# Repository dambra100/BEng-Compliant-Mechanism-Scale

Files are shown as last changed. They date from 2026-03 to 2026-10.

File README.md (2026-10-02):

# Optical Force Tracking: Compliant Mechanism Scale





This repository contains the software architecture, CAD, and raw datasets for a low-cost optical tracking scale. The system explores the replacement of expensive mechanical load cells with compliant mechanisms and computer vision (tracking planar displacements via a standard webcam).

**📄 Submitted for peer review to IEEE Sensors Letters; not accepted for publication. A preprint is publicly available on TechRxiv (August 2023). The submitted manuscript is also included in the `/Documents` directory.**

## 🔬 Core Technologies

### 1. Mechanical Design & FEA
The scale utilises a custom 3D-printed compliant mechanism. Extensive Finite Element Analysis (FEA) was conducted to ensure the flexure legs operate strictly within the elastic region of the PLA material, guaranteeing repeatability and preventing mechanical yielding under load.

### 2. Optical Tracking & GUI (MATLAB)
The system tracks physical planar displacements using high-contrast optical markers. 
* A custom MATLAB GUI (`gui.m`) segments the live video feed into four distinct quadrants.
* The software calculates 12 real-time state variables (pixel areas and centroid X/Y coordinates) to track micro-deformations.

### 3. Mathematical Calibration (Machine Learning)
Using Multiple Linear Regression (MLR) trained on 99 physical test samples, the system generates a `3×12` calibration matrix. 

## ⚙️ Engineering Workflow

* **Theoretical Validation:** Computational stress limits were established using CAD and FEA.
* **Physical Assembly:** The compliant mechanism was 3D printed and assembled with high-contrast optical markers.
* **Data Acquisition:** Eccentric load testing was conducted to capture raw displacement telemetry via the MATLAB computer vision interface.
* **Mathematical Isolation:** The calibration matrix successfully calculates absolute mass ($F_z$) while mathematically ignoring bending moments ($M_x, M_y$) caused by off-centre loads.

## 📁 Repository Structure

* `/CAD/` - Iterative design files (`.step`) and final 3D printing meshes (`.stl`).
* `/Documents/` - Final BEng dissertation report and the IEEE Sensors Letters submission manuscript (not accepted for publication; preprint available on TechRxiv).
* `/Images/` - Visual assets for physical assembly, FEA modelling, and GUI demonstration.
* `/Scripts/` - Core MATLAB optical tracking (`gui.m`), machine learning calibration, and plotting scripts.
* `ALL_IN_ONE.xlsx` - The raw 99-sample calibration and validation dataset.
* `README.md` - Project documentation.

## 📊 Execution & Results

### Physical Assembly & Hardware Testing
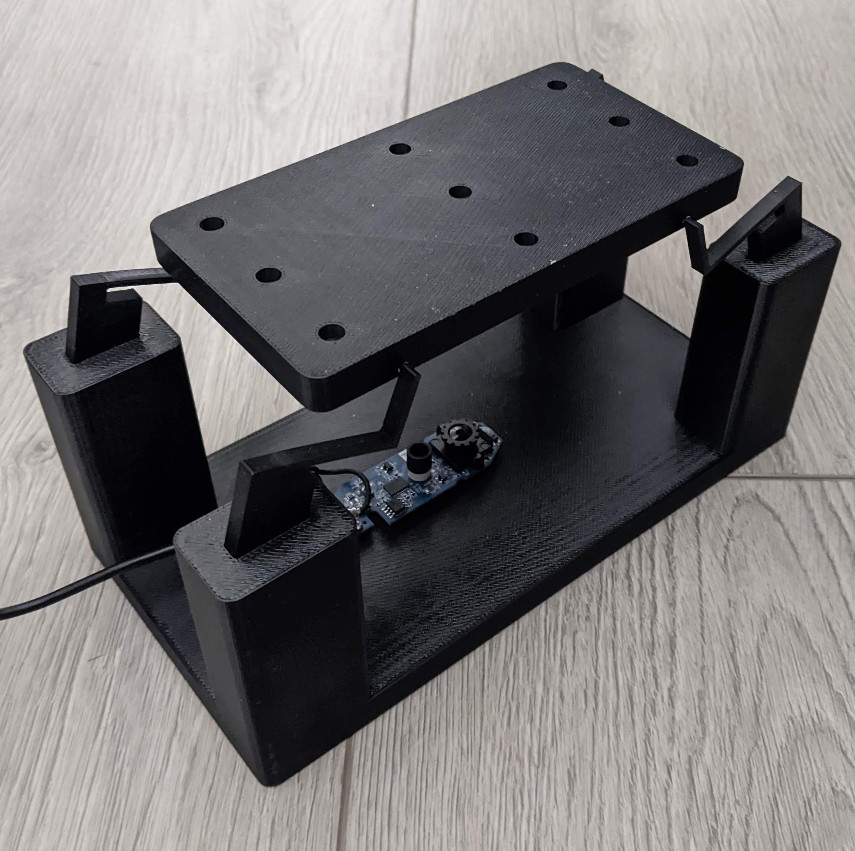
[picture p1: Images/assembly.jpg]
Physical Assembly

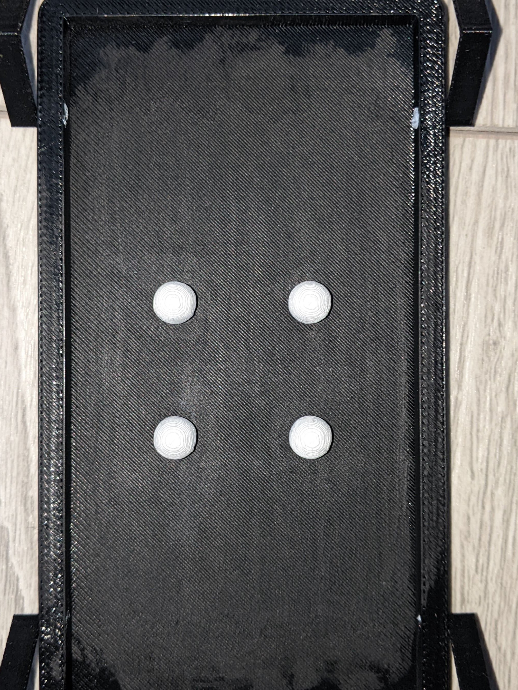
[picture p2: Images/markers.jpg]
Optical Tracking Markers

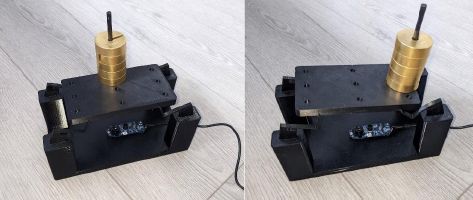
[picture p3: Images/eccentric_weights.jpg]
Eccentric Weights Testing


### FEA Stress Analysis
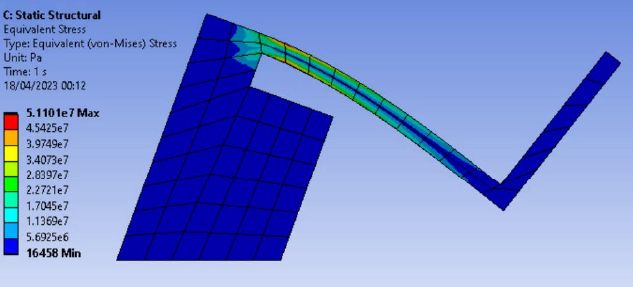
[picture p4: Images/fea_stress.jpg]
FEA Analysis


### Digital Pipeline & Validation
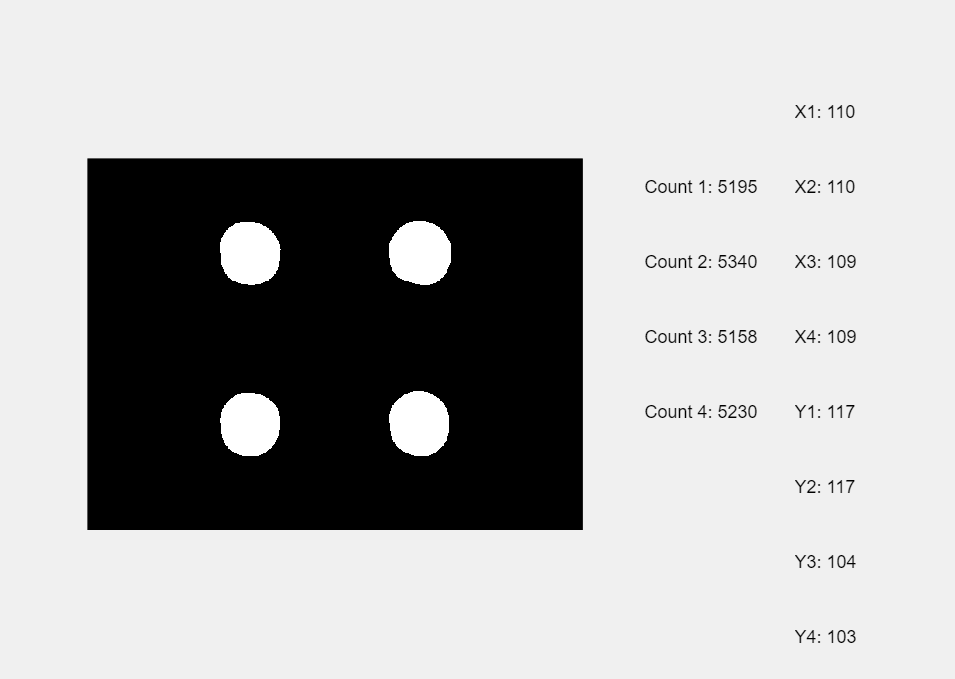
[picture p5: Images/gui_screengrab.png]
MATLAB GUI

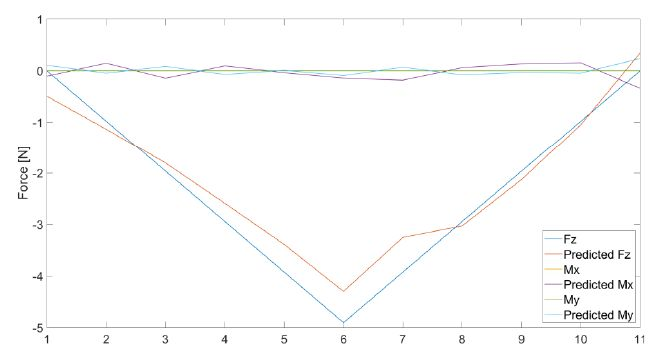
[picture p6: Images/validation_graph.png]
Performance Graph


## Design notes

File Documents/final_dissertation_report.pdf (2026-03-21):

DEPARTMENT OF MECHANICAL AND AEROSPACE ENGINEERING

FINAL PROJECT REPORT for

Development of a low-cost portable scale with a smartphone

by

Mohammad Zeshaan Shahid

Student ID: 1914982

Supervisor: Yohan Noh

Submitted in part fulfilment of the requirements for

the degree of Bachelors of Engineering

in

Mechanical Engineering

APRIL 2023

i

DECLARATION

I declare that the work in this project was carried out in accordance with the

requirements of the University’s Regulations and Code of Practice for Taught

Programmes and that it has not been submitted for any other academic award. Except

where indicated by specific reference in the text, this work is my own work. Work done

in collaboration with, or with the assistance of others, is indicated as such. I have

identified all material in this dissertation report that is not my own work through

appropriate referencing and acknowledgement. Where I have quoted or otherwise

incorporated material, which is the work of others, I have included the source in the

references. Any views expressed in the dissertation, other than referenced material,

are those of the author.

SIGNED: | | DATE: 01/03/23

ABSTRACT

This project aims to develop a low-cost portable scale using a smartphone. The project is

carried out to show that image processing technology can be used as a tool to find the weight

of an object. The project was carried out by 3D printing a platform on which a PCB of a webcam

was mounted. The webcam would then observe four white markers on a black surface, and

when a mass is placed on the platform the size of each marker and the distance of each

marker from the middle point can be found using the Image Processing Toolbox on MATLAB.

Using this data the mass can be found. In order to calibrate the sensor fixed masses are

placed. The main conclusion of this project is that it shows that an image-processing tool can

be effectively used to find the mass of an object.

ii

ACKNOWLEDGEMENTS

I would like to thank Professor Yohan Noh for their continued support throughout this project.

iii

TABLE OF CONTENTS

KEYWORDS | Error! Bookmark not defined.

iv

Appendices | XLI
Appendix A – Management of the Project | XLI
Appendix A.1 Project Gantt Chart | XLII

XLII

Appendix B – GUI MATLAB Script | XLIII
Appendix C – Plotting MATLAB Script | XLVI
Appendix D – Calibration MATLAB Script | XLIX
Appendix E – Risk Assessment | LII

v

LIST OF FIGURES

Figure Ref Title | Page

Figure 25: Characteristic curve between the loads Fz Mx, and the pixel count........ 29

Figure 28. Comparison between real Fz Mx and estimated Fz Mx (Positive Mx ).... 30

Figure 29. Comparison between real Fz Mx and estimated Fz Mx (Negative Mx ) .. 31

Figure 30. Comparison between real Fz My and estimated Fz My (Positive My ).... 31

vi

Figure 31:. Comparison between real Fz My and estimated Fz My (Negative My) .. 31

LIST OF TABLES

Table Ref Title | Page

vii

NOMENCLATURE

Abbreviations

CAD – Computer Aided Design

FEA – Finite Element Analysis

3D – Three-Dimensional

PLC – Programmable Logic Controller

RGB – Red, Green, Blue

CNN – Convolutional Neural Network

SVM – Support Vector Machine

HSV – Hue, Saturation, Value

BGR – Blue, Green, Red

MBR – Minimum Bounding Rectangle

GLCM – Grey-Level Co-occurrence Matrix

GUI - Graphical User Interface

### 1 Introduction

The development of portable weighing scales has become increasingly important in

many industries, such as agriculture, food processing, and shipping. These scales

allow for accurate and efficient weighing of goods, minimizing the risk of error and

reducing costs. However, the cost of traditional weighing scales can be prohibitive for

many small businesses and individuals. Additionally, traditional scales can be bulky

and difficult to transport, limiting their usefulness in certain contexts. To address these

challenges, this dissertation focuses on the development of a low-cost, portable scale

that utilizes a smartphone and an image processing tool to accurately measure the

mass of objects. By using a smartphone camera and a custom image processing

algorithm, this scale offers a low-cost, flexible, and user-friendly solution for measuring

the mass of goods in a variety of settings. The research presented in this dissertation

aims to demonstrate the feasibility and effectiveness of this approach and to explore

the potential applications and benefits of such a technology in various industries.

### 1.1 Context for the project

This project is relevant to the degree course in Mechanical Engineering because it

requires the use of the following:

- CAD Software
- Computer Language
- FEA Software

This project will enhance the strengths of the listed software, all of which are commonly

required in the industry.

A CAD software is needed to design the scale's portable folding/unfolding mechanism.

A computer language is needed to use an image-processing tool, which will be used

to read the number of pixels under the plate of the scale and the distance from the

centre point. An FEA software is needed to identify a suitable material and design for

the mechanism as it must remain in the elastic region when under loads of up to 5N.

The industrial relevance of this project is that it means people will be able to use this

device to weigh things without needing an actual scale. All they need is this device

and a smartphone, so unlike traditional small electrical scales, there is no need for any

batteries. Instead, all they need is a charged smartphone that has a camera.

The coding language MATLAB will be used because it is based on a matrix data

structure which makes it ideal for image processing. Image processing operations that

might require many lines of code in other coding languages can be expressed in a

single line of MATLAB code.

The CAD software that will be used is Fusion 360. Fusion 360 will be used because

of prior knowledge on the software. Other advantages of Fusion 360 are that it has

cloud based saving and also has a wide range design tools which makes creating

complex geometries easier

The FEA software of choice will be Ansys Workbench as it has a good interface and

is easy to use. It also has a wide range of simulation capabilities and advanced

material modelling.

There can offer many commercial aspects of this project as having a small portable

weighing scale that uses a smartphone and an image processing tool would be:

Convenient: The scale will be able to be easily carried around, making it convenient

to weigh small items on the go.

Cost-effectiveness: It can be produced at a lower cost compared to traditional

weighing scales

Accuracy: Using an image processing tool the scale can achieve a higher accuracy

meaning it can be used for scientific medical and industrial purposes.

Flexibility: The scale can be used with a variety of smartphones and other mobile

devices, making it more versatile and adaptable to the needs of various users.

There are current weighing scales which use image processing technology on the

market but they tend to use edge detection and pattern recognition rather than

observing different markers. Many smartphones do not have the computational

power or the memory capacity to perform pattern recognition as it typically involves

training a machine learning algorithm.

### 1.2 Aim and objectives for the project

The aim of this project is to develop a low-cost portable scale that utilizes a

smartphone and an image processing tool to accurately measure the mass of objects.

The specific aims of this project are:

- To develop an image processing algorithm that accurately measures the mass

of objects using a smartphone camera.

- To design and develop a prototype of the portable scale that incorporates the

image processing algorithm.

- To evaluate the accuracy and precision of the portable scale in comparison to

traditional weighing scales.

- To explore the potential applications of the portable scale in various industries,

including agriculture, food processing, and shipping.

To achieve the aims of this project, the following objectives will be pursued:

- Conduct a comprehensive literature review of existing portable scales, image

processing algorithms, and smartphone-based measurement tools.

- Develop an image processing algorithm that can accurately measure the mass

of objects using a smartphone camera.

- Design and develop a prototype of the portable scale that incorporates the

image processing algorithm.

- Test the accuracy and precision of the portable scale by comparing it to

traditional weighing scales using a range of objects and masses.

- Write a report summarizing the findings of the project and making

recommendations for future development and implementation of the portable

scale.

### 2 Literature Review

### 2.1 Introduction

This literature review focuses on a project that aims to create a low-cost portable scale

using a smartphone and image processing technology. The primary objective of the

review is to provide a comprehensive overview of the existing knowledge, techniques,

and technologies relevant to the proposed project. It will explore a range of topics,

including smartphone-based measurement tools, the use of image processing

techniques, current calibration and validation methods, and related works in the field,

to demonstrate the feasibility of the proposed project and provide a solid foundation

for its development.

### 2.2 Background

The importance of accurate and convenient weight measurement systems cannot be

understated, as they play a critical role in various industries. Traditional weight

measurements devices, such as mechanical scales, electronic balances, and load

cells, are widely used but often come with limitations in terms of cost, portability, and

ease of use. With the rapid advancement of technology, there is a growing interest in

developing alternative, low-cost, and portable solutions that leverage the power of

smartphones and image-processing technology. Despite these technological

advancements, there are still challenges and limitations to overcome in developing an

accurate and reliable low-cost portable scale based on smartphones and image

processing technology. This literature review aims to provide a comprehensive

understanding of the current state of the field and the relevant technologies, such as

portable scales, image processing techniques, smartphone technology and sensors,

and calibration methods. By identifying the gaps and limitations in existing

approaches, this review will lay the foundation for the development of a low-cost

portable scale using a smartphone and image processing technology, with the

potential to revolutionize weight measurement systems.

### 2.3 Smartphone-based Measurement Systems

Over the past few years, smartphones have evolved into highly advanced,

multifunctional devices equipped with a plethora of sensors and processing

capabilities. This rapid development has allowed researchers and engineers to

leverage smartphones for various measurement systems, utilizing their in-built

sensors, computing power, and portability. In this section, we will discuss the current

state of smartphone-based measurement systems, highlighting their applications,

advantages, and limitations.

### 2.3.1 Applications of Smartphone-based Measurement Systems

Smartphone-based measurement systems have found applications across diverse

fields such as healthcare, transportation, environmental monitoring, and industrial

automation. Some notable examples include:

Health monitoring: Smartphones have been used to monitor heart rate, blood

pressure, and physical activity levels using in-built or external sensors. Mobile

applications have also been developed for diagnosing and managing chronic

conditions such as diabetes or sleep disorders. For instance, Cardiio is a mobile app

that uses a smartphone's camera to measure an individual's heart rate through non-

contact photoplethysmography. [1] [2]

Transportation and navigation: Smartphones' integration of GPS, accelerometers, and

gyroscopes has facilitated precise location tracking and navigation capabilities,

enabling better transportation management and route optimization. Google Maps is a

prominent example of smartphones being used for this purpose. [3]

Environmental monitoring: Smartphone sensors such as microphones and cameras

have been employed to assess noise pollution, air quality, and other environmental

factors in real time. For example, the AirVisual app provides real-time air quality data,

forecasts, and historical trends by aggregating data from various sources. [4]

Industrial automation: Smartphones have been used as data acquisition and control

devices in industrial processes, enabling remote monitoring, maintenance, and

efficient resource management. Mobile apps for Programmable Logic Controllers

(PLCs) are an example of smartphones being used in industrial automation. These

apps communicate with the PLCs through wireless networks, allowing users to access

the PLC from anywhere with an internet connection. [5]

### 2.3.2 Advantages of Smartphone-based Measurement Systems

The increasing popularity of smartphone-based measurement systems can be

attributed to several advantages they offer:

Cost-effectiveness: As smartphones are widely available and include multiple sensors,

their utilization in measurement systems can reduce the need for dedicated, costly

hardware.

Portability: The compact and lightweight nature of smartphones enables users to carry

and deploy measurement systems effortlessly, facilitating measurements in various

locations and scenarios.

Accessibility: Smartphone-based measurement systems can reach a broader

audience, given the widespread use of smartphones worldwide. This accessibility can

potentially enhance data collection, knowledge sharing, and problem-solving across

different domains.

Versatility: The combination of diverse sensors and powerful processing capabilities

in smartphones allows for versatile measurement systems, capable of addressing a

wide range of applications.

### 2.3.3 Limitations of Smartphone-based Measurement Systems

Despite the numerous advantages, there are certain limitations to consider when using

smartphones for measurement systems:

Sensor accuracy and variability: The accuracy of sensors embedded in smartphones

can vary between different devices and models, potentially affecting the reliability of

the measurement system.

Power consumption: Continuous use of sensors and processing capabilities can drain

the smartphone's battery, limiting the measurement system's operational time.

Data privacy and security: The use of smartphones for data collection and

transmission may raise concerns about data privacy and security, necessitating robust

data protection mechanisms.

In conclusion, smartphone-based measurement systems offer a cost-effective,

portable, and accessible alternative to traditional measurement tools. By

understanding and mitigating their limitations, these systems can significantly impact

various industries, enhancing efficiency and decision-making processes. The low-cost

portable scale developed in this project is one such example of an innovative

smartphone-based measurement system, showcasing the potential of image

processing technology in estimating object weight.

### 2.4 Image Processing for Weight Estimation

Image processing has become an essential tool in various fields due to advancements

in computer vision and machine learning techniques. The capability of extracting

meaningful information from images has led researchers to explore the potential of

using image processing for weight estimation and other physical property

measurements. In this section, we will discuss the different approaches and

methodologies adopted in the literature for weight estimation using image processing

techniques.

### 2.4.1 Approaches for Weight Estimation

Several approaches have been proposed to estimate an object's weight based on its

appearance in images. Some of the most common methods include Shape and size

analysis: By analysing the object's shape and size in images, researchers can develop

models to estimate the object's weight. For instance, the size of fruits or fish has been

correlated with their weight, allowing for weight estimation based on their dimensions

in images. [6] [7]

Volume estimation: In some cases, the weight of an object can be estimated by first

calculating its volume from images. Techniques such as stereo vision or depth sensors

can be employed to obtain 3D information and subsequently calculate the volume of

the object. This approach has been used for estimating the weight of irregularly

shaped objects, such as logs or rocks. [8] [9]

Deformation analysis: Another approach for weight estimation is based on observing

the deformation of an object or a supporting structure caused by the object's weight.

In the context of this project, image processing is used to track the displacement of

markers on a platform due to an object's weight. The displacement data can then be

used to infer the object's mass. [10]

Machine learning and deep learning: Advanced machine learning and deep learning

techniques, such as Convolutional Neural Networks (CNNs) and Support Vector

Machines (SVMs), have been used for weight estimation tasks. These algorithms can

learn complex patterns and relationships between image features and object weight

through training on large datasets. [11]

### 2.4.2 Challenges and Considerations

While image processing techniques have shown promise for weight estimation tasks,

there are several challenges and considerations to take into account:

Calibration and accuracy: Ensuring accurate weight estimation through image

processing requires proper calibration and validation using ground truth data. This can

be achieved by using known masses during the development and testing phases of

the system.

Image quality and lighting conditions: The accuracy of weight estimation can be

affected by variations in image quality and lighting conditions. It is crucial to consider

these factors while designing the measurement setup and developing the image

processing algorithms.

In summary, image processing techniques offer a promising alternative for weight

estimation tasks. By understanding and addressing the challenges and considerations

discussed in this section, accurate and reliable weight estimation can be achieved

using image-based methodologies. The project presented in this dissertation is a

testament to the potential of image processing technology in determining the mass of

an object through marker displacement analysis.

### 2.5 MATLAB Image Processing Toolbox

The Image Processing Toolbox is a comprehensive suite of tools and functions

available in MATLAB for processing, analysing, and visualizing images. The toolbox

offers a wide range of algorithms for various image-processing tasks, such as image

enhancement, segmentation, transformation, and feature extraction. In this section,

we will discuss the key features and capabilities of the MATLAB Image Processing

Toolbox and its relevance to the low-cost portable scale project using a smartphone.

### 2.5.1 Key Features and Capabilities

The MATLAB Image Processing Toolbox provides several features and capabilities

that facilitate image processing and analysis, including:

Image enhancement: The toolbox offers a variety of algorithms for enhancing image

quality, such as noise reduction, contrast adjustment, and filtering techniques. These

functions help improve the image's visual appearance, making it easier to analyse and

extract relevant information. [12]

Image segmentation: Segmentation is the process of dividing an image into

meaningful regions or objects. The Image Processing Toolbox provides various

segmentation algorithms, such as thresholding, region growing, and edge detection,

to separate and identify objects within an image. [13]

Spatial transformations: The toolbox includes functions for performing spatial

transformations on images, such as resizing, rotating, and warping. These functions

are useful for image registration, alignment, and geometric correction. [14]

Feature extraction: The Image Processing Toolbox allows for the extraction of features

from images, such as corners, edges, and blobs. These features can be used to

analyse the properties of objects in images or as input for machine learning algorithms.

[15]

Colour space conversion: The toolbox supports the conversion of images between

various colour spaces, such as RGB, HSV, and YCbCr. This functionality is useful for

colour-based image processing tasks, such as object recognition and tracking. [16]

### 2.5.2 Relevance to the Portable Scale Project

In the context of the low-cost portable scale project using a smartphone, the MATLAB

Image Processing Toolbox is employed for processing the images captured by the

smartphone camera and estimating the mass of objects based on marker size and

displacement. The toolbox's capabilities are particularly relevant in the following

aspects:

Image pre-processing: Enhancing the image quality by reducing noise, adjusting

contrast, and correcting lighting conditions, which is essential for accurate marker

detection and tracking.

Marker detection and tracking: The toolbox's segmentation, feature extraction, and

morphological operations can be used to identify and track the position of the four

white markers on the black surface.

Geometric transformations and analysis: The toolbox provides functions for calculating

the size of each marker, the distance between markers, and the displacement caused

by the mass placed on the platform. These measurements can be used to estimate

the object's mass.

In summary, the MATLAB Image Processing Toolbox offers a comprehensive set of

tools and functions for processing and analysing images, making it an essential

component of the low-cost portable scale project using a smartphone. By leveraging

the toolbox's capabilities, the project demonstrates the potential of image processing

technology as an effective tool for estimating the mass of objects based on marker

displacement analysis.

### 2.6 Previous Studies

Looking at previous studies, current methods using image processing tools to weigh

objects tend to focus on systems designed to weigh specific objects, rather than a

range of objects like traditional weighing scales. There is also currently no small

weighing scale that uses image processing.

An example of a study that used image processing study was carried out by

Duangkamol Dangphonthong and Wasan Pinate which uses the following method to

analyse the image and estimate the weight of an egg:

First, a colour image of the egg is captured using a digital camera, resulting in an RGB

image with a resolution of 3,000 x 4,000 pixels. The egg is placed in various positions

to test the accuracy of weight estimation.

Second, image sharpening is performed to adjust the contrast of the image. The

contrast is adjusted by determining the position of intensity changes, enabling the clear

identification of the object's edges.

Third, image representation is used to separate the relevant parts of the image, with

region representation used in this research. The egg's area is represented by the

number 1, while other areas are represented by the number 0.

Fourth, regional descriptors are used to determine the basic features of the object,

such as width, length, height, shape, and surface. In this research, the width and length

of the egg are calculated using the distance formula.

Fifth, egg weight and volume are computed using various equations proposed by

different researchers. This study uses the fourth equation to estimate egg volume, and

the extrapolation method is used to estimate egg weight based on the relationship

between weight and volume.

Finally, recognition involves sorting egg size by weight and comparing the analysed

egg weight with the agricultural commodity and food standard. This helps in classifying

the eggs according to their sizes. [17]

Another example of a study that used image processing was carried out by Sharma,

R., Kumar, M. & Alam, M.S. which uses the following method to categorize wheat

samples into sound, damaged, shrivelled, and broken grains:

First, the acquired colour images in BGR format were converted into three 8-bit

grayscale images, representing the blue, green, and red bands. This simplifies the

analysis by reducing the amount of data to be processed and focusing on intensity

values.

Next, a low-pass Gaussian filter with a 5x5 kernel size was applied to the grayscale

images to remove small discrepancies or noise, ensuring smoothness and preserving

the important details in the images. After that, the combined thresholding algorithm of

binary and Otsu operator was applied for background segmentation using the OpenCV

threshold function. This technique helps in separating the desired object, such as

wheat grain, from the background. Binary thresholding was used for other refractions,

like damaged, shrivelled, and broken grains.

A mask was created based on the threshold values, and bitwise operations were

performed to keep only the pixels in the desired range, thus segmenting the grains

effectively. Following this, OpenCV's CHAIN_APPROX_NONE function was used to

detect the contours of each binary image of grain. This step involves finding the

boundaries of the grains in the images, which are then used for extracting size, shape,

colour, and texture features.

RGB images were converted to HSV (Hue, Saturation, Value) colour space using

OpenCV's BGR2HSV function. The HSV model is closer to human colour perception,

making it more suitable for colour feature extraction.

Finally, a range of features was extracted using OpenCV library functions, including

area, perimeter, solidity, minimum bounding rectangle (MBR), major and minor

diameter, equivalent diameter, and more. Additionally, colour and texture feature like

grey-level co-occurrence matrix (GLCM) were extracted using the skimage library.

These image processing techniques allowed for the systematic extraction of size,

shape, colour, and texture features of the wheat kernels, which are essential for

various analysis and classification tasks in agriculture. [18]

### 3 Methodology

### 3.1 Introduction

The methodology section of this project provides a detailed and systematic description

of the steps and processes followed to develop a low-cost portable scale using a

smartphone's rear camera and a folding/unfolding mechanism. This section aims to

ensure that the project's approach is transparent and reproducible, allowing others to

understand, evaluate, and potentially build upon the work. In this section, we will

outline the methods used for selecting the appropriate CAD software and

programming language, designing and refining the portable scale and folding

mechanism, implementing the computer vision application and graphical user

interface (GUI), and calibrating and validating the system's performance.

### 3.2 Selection of CAD Software and Programming Language

To select the most suitable CAD software and programming language for this project,

a set of criteria was established to evaluate and compare the available options. These

criteria included ease of use, availability of tutorials and resources, compatibility with

computer vision libraries and integration capabilities.

### 3.2.1 Selection of CAD Software

After considering various CAD software packages, including CREO, Fusion 360,

Onshape, Solidworks, and Ansys, Fusion 360 was chosen for the following reasons:

Fusion 360 is a CAD software that offers several benefits to its users. One of its

advantages is its user-friendly interface, which makes it easier for new users to learn

and become proficient in designing. Additionally, Fusion 360's cloud-based

functionality enables seamless collaboration and remote access to project files,

making it convenient for teams working on the same project. The software also offers

comprehensive features that include parametric design, direct modelling, assembly,

and FEA capabilities, which help streamline the design process. Moreover, Fusion 360

has a strong community support system, which includes an active user community and

a wealth of online resources such as tutorials and forums that provide assistance in

the learning process and troubleshooting support.

### 3.2.2 Selection of Programming Language

When evaluating programming languages, options like Python, C++, C#, and MATLAB

were considered. MATLAB was chosen due to the following factors:

MATLAB is a programming language that offers several advantages for image

processing and computer vision tasks. One of its strengths is its extensive library

support, which includes built-in functions and toolboxes such as the Image Processing

Toolbox and Computer Vision Toolbox, that are well-suited for these tasks.

Additionally, MATLAB's syntax is straightforward and easy to understand, promoting

the development of complex algorithms and reducing the likelihood of coding errors.

The software also provides comprehensive documentation and has an active user

community, which makes it easier to find solutions and guidance for implementing

specific functions and algorithms. Overall, MATLAB is a powerful tool for image

processing and computer vision tasks that offers simplicity, readability, and strong

community support.

In conclusion, Fusion 360 and MATLAB were selected for this project based on their

user-friendly interfaces, compatibility with each other, comprehensive features and

strong community support. These tools provide an ideal foundation for the

development of the low-cost portable scale system using a smartphone's rear camera

and a folding/unfolding mechanism.

### 3.3 Conceptual design and design refinement

The key concept from the beginning was that there will be a camera looking up at a

surface which has four different spherical markers. When a mass is placed on the main

body, the legs of the mechanism will deform, causing the size of the markers to

increase. Based on the sizes of the markers the weight will be calculated. Later in the

project, to improve the accuracy of the scale, the distance of these four markers from

the centre point was also used. By calculating the X and Y distance of each marker,

the calibration matrix goes from 3x4 to 3x12.

The first mechanism that needed to be designed was the folding and unfolding

mechanism. The initial inspiration for the final design is taken from folding picnic tables

like the one seen below in Figure 1

Figure 1: Folding picnic table [19]

Next, a design for the leg had to be created. The leg design had to be created so that

the mechanism can deform under loads of up to 500g and stay within the elastic

region. To create different concepts for the leg Autodesk Fusion 360 was used. Below

in Figure 2 you can see the leg designs that were considered to take into further testing

using FEA:

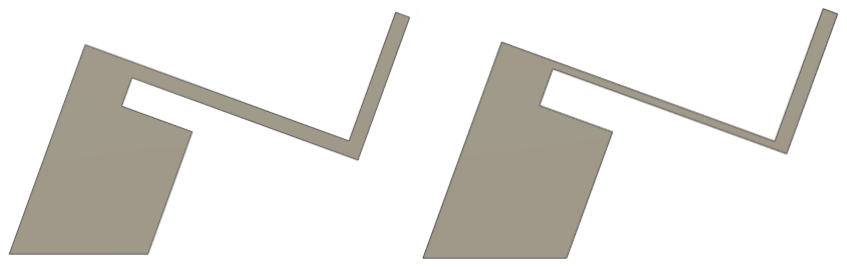
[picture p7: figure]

Figure 2: Concept leg designs

The inspiration for the leg designs was cantilever beams, this is because cantilever

beams have many advantages, the key advantage in this application is that they offer

large deflection. Greater deflection is beneficial because it means a greater change in

pixel size and distance making the scale accurate for smaller masses. Another

advantage of the cantilever beam is that it doesn’t require support on the opposite

side. The cantilever beam design also means the deformation can be controlled and

predicted.

Later, due to the irregular shape of the legs rather than having the leg fold, it was

chosen to have the supports of the base fold instead. The folding mechanism can be

seen later in Figure 4. The legs are able to fold due to the hinge, as the hinge is very

thin it is able to easily fold and unfold. If the product was to be mass-produced a metal

hinge would likely be used to ensure the longevity of the product.

The main body for the scale was designed next, with the legs and base taken into

consideration. The body is designed with 9 holes used to place a cylinder which will

be used later for the calibration process. The main body is also designed with 4 holes

on the sides seen later in Figure 5 to connect the legs. At the bottom of the main body,

there are four white spherical markers which will be what the camera detects, the

markers can be seen later in Figure 6.

Rather than using an actual smartphone, a webcam was used as it would be able to

be mounted to the base and can be easily connected to a computer via USB. The

webcam of choice was the Logitech C270 HD WEBCAM. This webcam was chosen

because it doesn’t have any auto-focus features. This is beneficial because it will give

a consistent image which will improve repeatability. In order to mount the webcam

PCB needed to be removed from its casing. To remove the PCB from the casing firstly,

the top cover needs to be removed. Secondly, the front cover needs to be unscrewed

and removed. Then, the PCB should be unscrewed from the casing. Finally, to remove

the wire, a hot knife should be used to cut the casing. By following these steps, the

device can be disassembled effectively and safely.

Looking at the PCB because of the connecting cable at the bottom of the PCB, seen

in Figure 3 two raised holes were created in the base in order to screw into PCB onto

the base, as seen later in Figure 6.

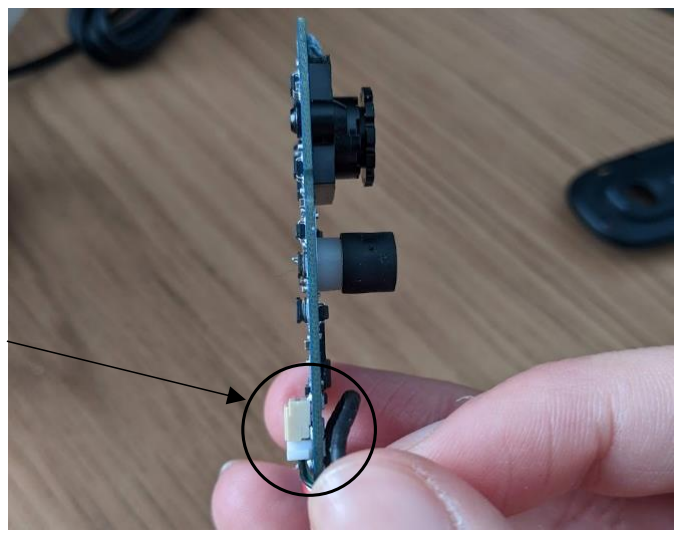
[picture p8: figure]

Figure 3: Webcam PCB

The model was planned to be 3D printed, and the material of choice was either PLA

(Polylactic Acid) or ABS (Acrylonitrile Butadiene Styrene). ABS was chosen because

generally, ABS has higher elasticity than PLA, meaning it will return to its original

shape relatively quickly. Other advantages of ABS over PLA are; better impact

resistance, higher temperature resistance and greater durability.

### 3.4 CAD Modelling

Following the concept design, the individual parts and the complete model were

created in Fusion 360.

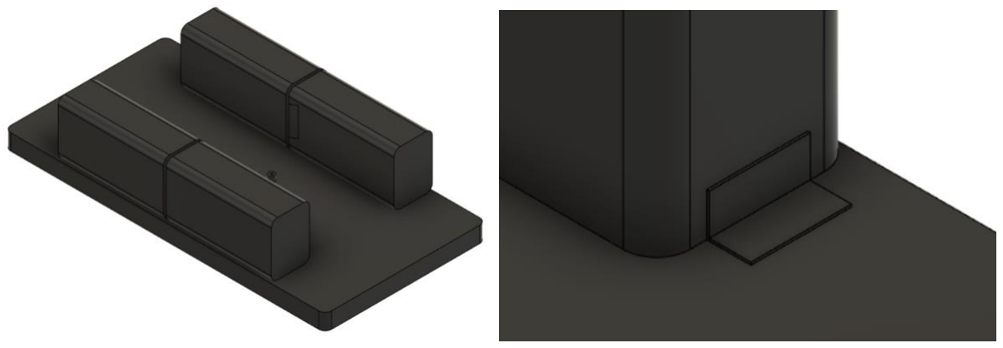
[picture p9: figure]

Figure 4: Folding Mechanism and Folding Hinge

Connecting cable

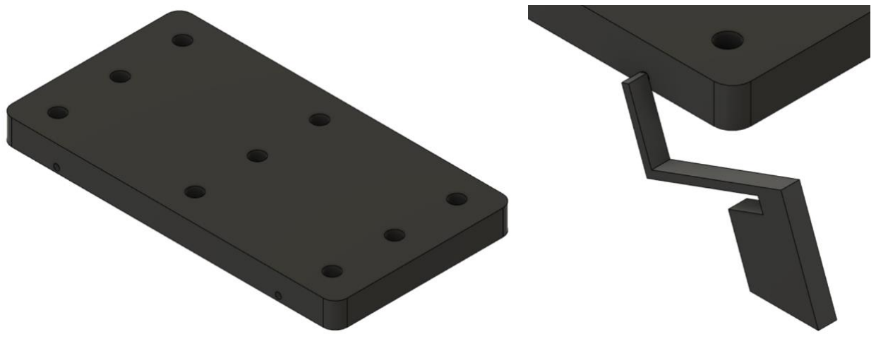
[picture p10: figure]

Figure 5: Main Body and Leg

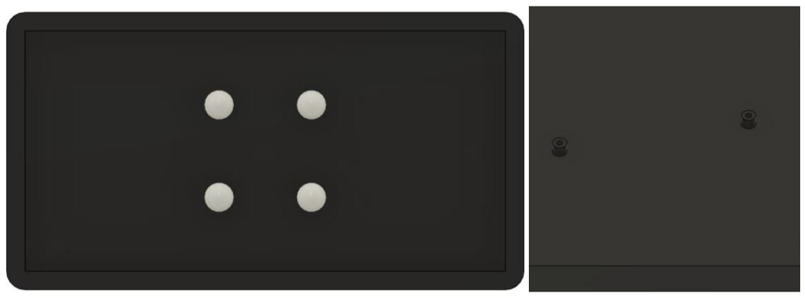
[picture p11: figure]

Figure 6: Main Body with Markers and Base raised Holes

### 3.5 FEA

Below are the properties used for the ABS within Ansys Workbench:

- Density: 1.3 g/cm^3
- Elastic modulus: 2.5 GPa
- Poisson's ratio: 0.45
- Yield strength: 55 MPa
- Ultimate tensile strength: 65 MPa

Firstly, the four concept designs for the leg were put under loads of 5 N (500 g)

Below, in Figure 7 you can see how the force is applied and the fixed support.

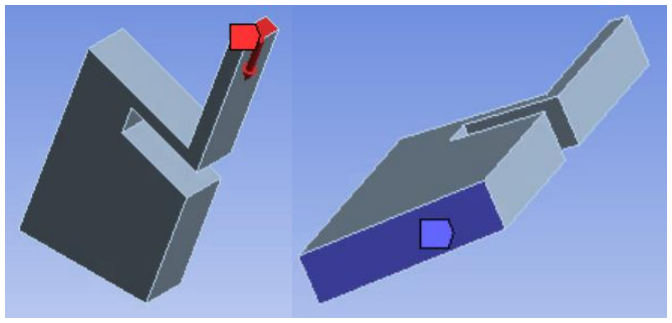
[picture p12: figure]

Figure 7: Force and Fixed Support in Ansys Mechanical

Below in Figures 6-11 are the total deformations for the four concept designs

Figure 8: Total Deformation of Concept Leg 1

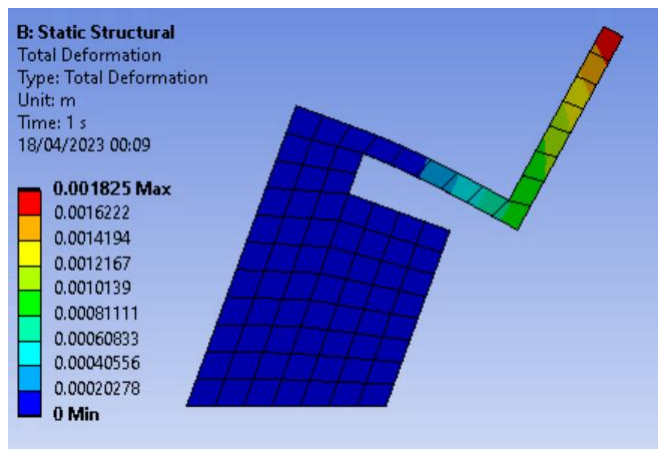
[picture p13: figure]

Figure 9: Total Deformation of Concept Leg 2

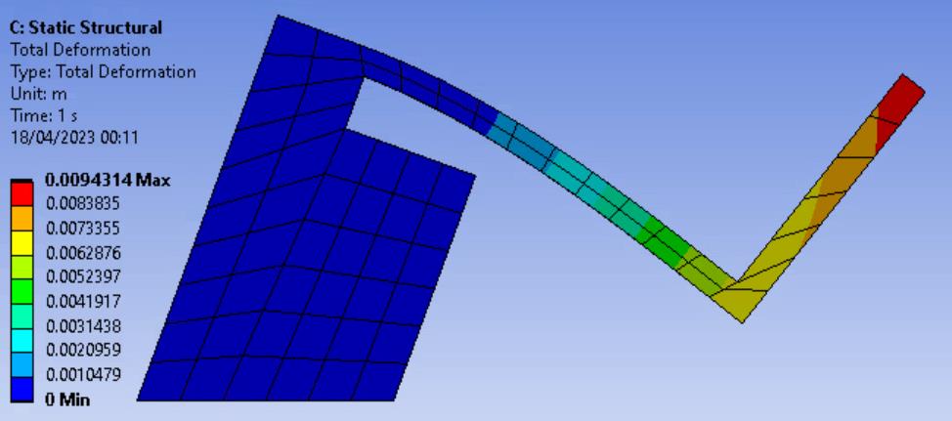
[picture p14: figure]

Figure 10: Total Deformation of Concept Leg 3

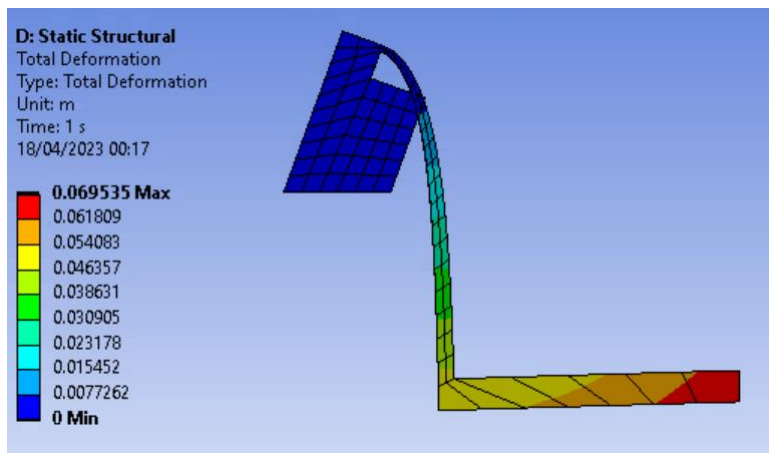
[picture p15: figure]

Figure 11: Total Deformation of Concept Leg 4

At this point, Concept Design 4 can be ruled out due to excessive deformation

Below in Figures 12-14 are the Equivalent Stresses for the remaining three concept

designs

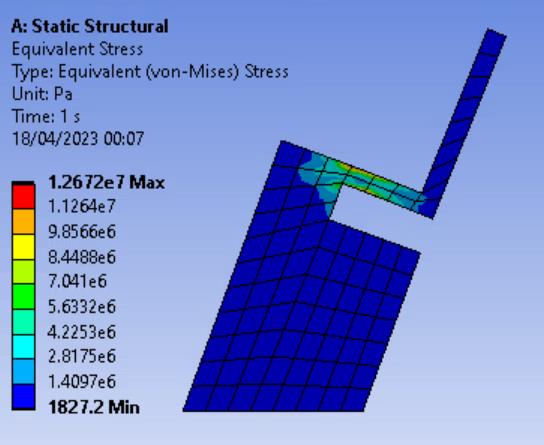
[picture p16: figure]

Figure 12: Equivalent Stress of Concept Leg 1

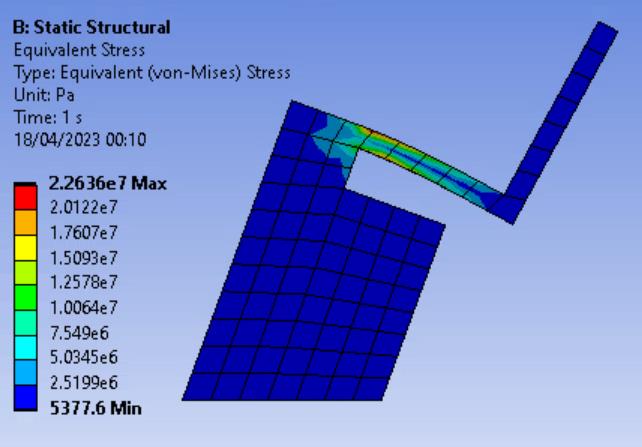
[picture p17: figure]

Figure 13: Equivalent Stress of Concept Leg 2

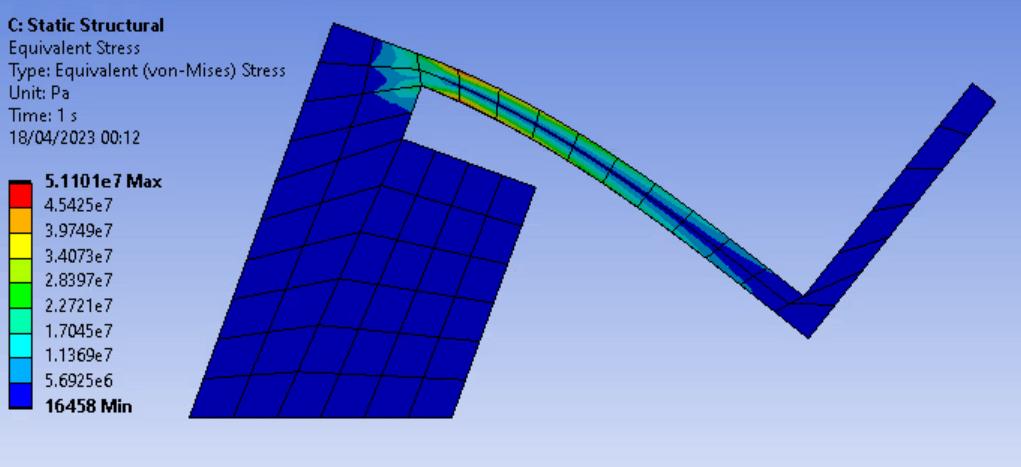
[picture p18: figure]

Figure 14: Equivalent Stress of Concept Leg 3

It can be seen that none of the equivalent stresses exceeds the yield stress of 55 MPa

therefore all designs will stay within the elastic region and there will be no permanent

deformation. Therefore, Concept Leg 3 was chosen due to having the largest amount

of deformation without any points on the leg coming in contact with each other.

Using the results from the FEA, the design for the final model was finalised and created

using CAD, as seen below in Figure 15

Figure 15: Complete CAD model

Next, the total deformation of the entire model was also predicted using FEA. Below

in Figures 16-19 are the predicted deformations for the different positions:

Figure 16: Predicted deformation when on Fz is applied

Figure 17: Predicted deformation when Fz, Mx and My are applied

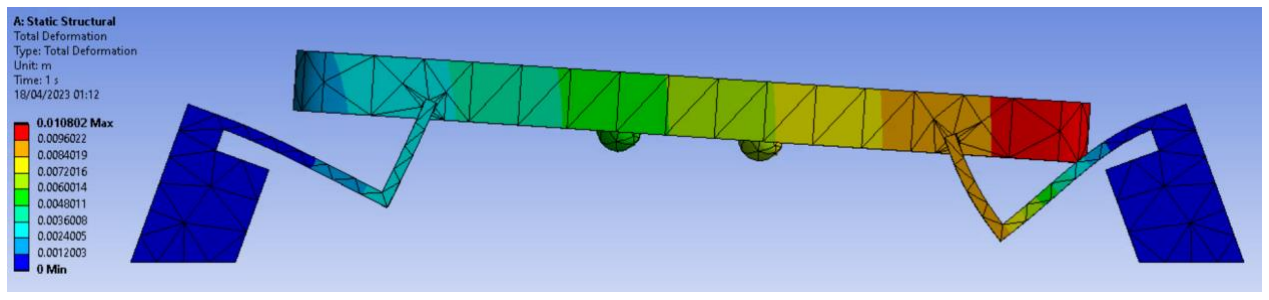
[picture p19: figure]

Figure 18: Predicted deformation when Fz and Mx are applied

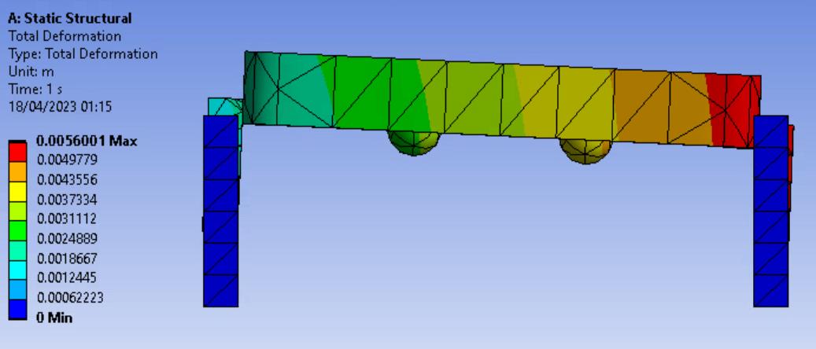
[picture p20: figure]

Figure 19: Predicted deformation when Fz and My are applied

### 3.6 Development of the MATLAB code

The code was then developed within MATLAB, during testing of the code rather than

using a webcam image a .jpg image was used instead. Once the code was tested, the

webcam was included.

Below is a detailed description of the steps within the code:

1. Initialize the camera by creating a webcam object named 'cam'.
2. Create the GUI window with specified dimensions and a title called 'Image

Analysis'.

3. Define the image axes inside the GUI window to display the captured images.
4. Create labels in the GUI to display the number of white pixels, centroid

positions of white pixels in four equal sections of the processed image and

mass

5. Create a main loop that continues running as long as the GUI window is open:
a. Capture an image from the camera.

b. Apply a Gaussian filter to the image to smooth it and reduce noise.
c. Convert the filtered image to a binary (black and white) image.
d. Divide the binary image into four equal sections.
e. Count the number of white pixels in each section.
f. Compute the centroid positions of the white pixels in each section.
g. Calculate the X and Y distances of each centroid from the centre of the

whole image.

h. Calculate the mass using the centroid positions, X and Y distances and

the calibration matrix

i. Display the binary image and the results (white pixel count, centroid

positions and mass) in the GUI.

6. When the GUI window is closed, clean up by deleting the camera and GUI

objects.

Below Figure 20 shows how the centroid positions are calculated:

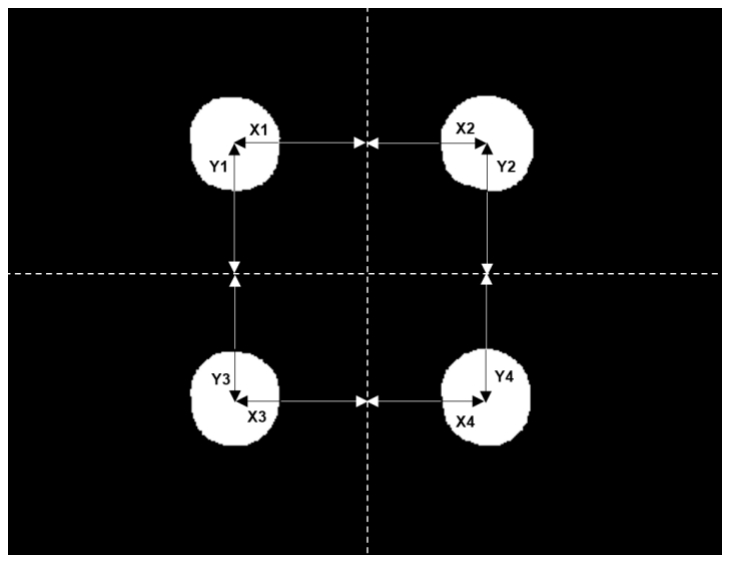
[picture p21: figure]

Figure 20: Graphic showing how the centroid positions are calculated

In summary, this code captures images from a webcam, processes the images by

applying a Gaussian filter and converting them to binary, and then divides the images

into four equal sections. It computes the number of white pixels and their centroid

positions in each section and displays the results in a GUI window. The full code can

be found in Appendix B.

### 3.7 Prototype fabrication and testing

The CAD models were then converted into STL (Standard Tessellation Language)

files and placed onto the virtual print bed with supports on the software UltiMaker Cura

5.2.2. The pre-defined profile was used for the print settings. The model is then sliced

and saved as a G-code. The G-code is then put onto a USB flash drive and loaded

onto the printer. The print bed is levelled and the correct filament is added. From here

the printing process can be started. Once the parts are printed, they are put into a

chemical bath. This is to remove any soluble support material and remove any excess

material that may have been left on the part after printing.

Once the parts were ready, the four markers on the main body needed to be painted

white, this was done using white acrylic paint. Next, the webcam PCB was mounted

onto the base and the legs were attached to the main body. Finally, the legs were then

connected to the base to complete the model.

Following this, the model was tested by placing 500g of mass onto each of the 9

positions of the main body to see the levels of deformation. Figure 21 shows the Fz

and Fz,Mx,My positions and Figure 22 shows the Fz,Mx and Fz,My positions

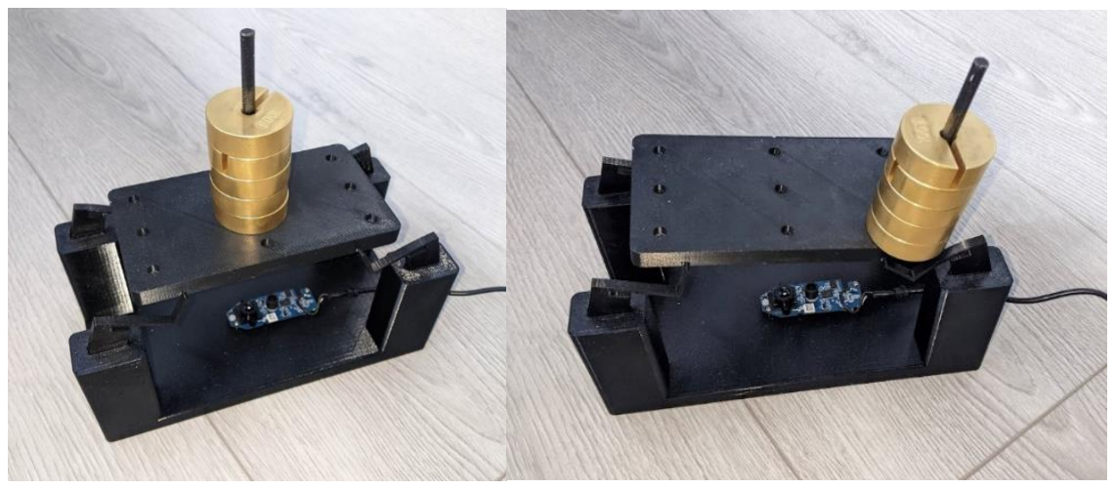
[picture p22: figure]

Figure 21: Testing of the deformation with Fz and Fz,Mx,My

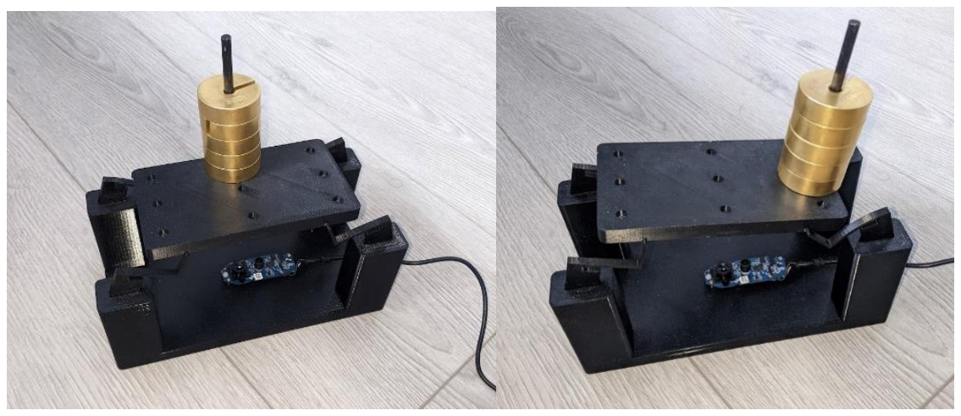
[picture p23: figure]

Figure 22: Testing of the deformation with Fz,Mx and Fz,My

The webcam image was also tested to see if the four white markers were clearly

visible. The webcam image can be seen below in Figure 23.

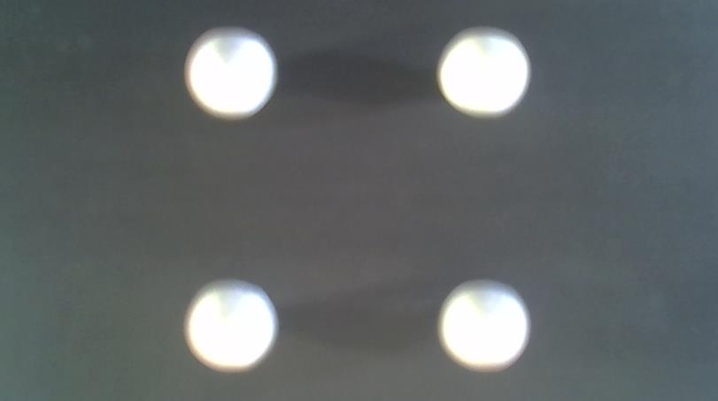
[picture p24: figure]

Figure 23: Webcam image showing the visibility of the four white markers

### 3.8 Calibration and validation

For the calibration process, first data was collected for each of the 9 positions on the

main body. This was done by using a separate MATLAB code which creates two

separate figures with a line plot, one for the white pixel counts and one for the X and

Y distance of the centroids. The full code can be found in Appendix C Using this code,

masses from 0g to 500g were placed in steps of 100g every 10 seconds. Then the

masses were removed from 500g to 0g in steps of 100g every 10 seconds. This was

repeated 3 times for all 9 positions.

By manually extracting the data from all of the graphs, the data is then put onto an

Excel spreadsheet. The Fz, Mx and My for each of the 9 positions can be calculated

using the X and Y distances of the positions from the centre point. This calibration

method is inspired by the research carried out in “ Three-Axis Fiber-Optic Body Force

Sensor for Flexible Manipulators” [20]

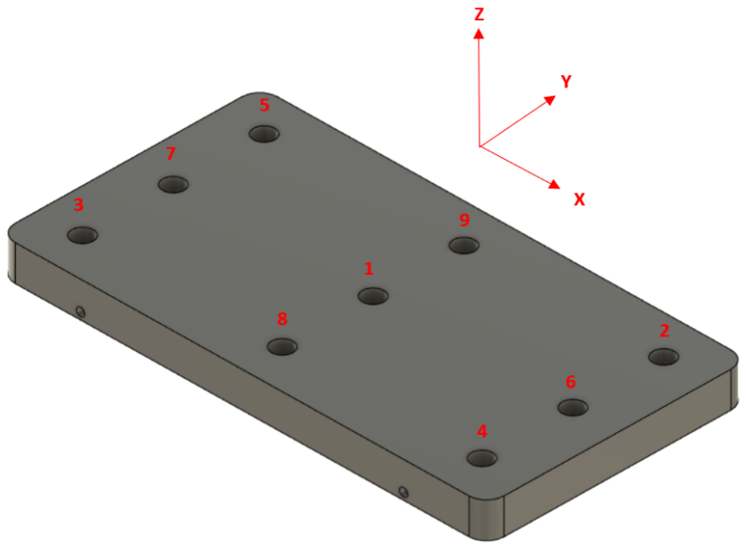
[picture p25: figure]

Figure 24: Main body with labels of the nine positions

Using the data from positions 1-5 in Figure 24 another MATLAB code is used to find

the calibration matrix. The calibration matrix is found by performing linear regression.

The full code can be found in Appendix D. Once the calibration matrix is found it can

be used to predict the Fz, Mx and My using the formula below:

[

Calibration
Matrix ] ×

[

Count 1
Count 2
Count 3
Count 4
X1 Distance
Y1 Distance
X2 Distance
Y2 Distance
X3 Distance
Y3 Distance
X4 Distance
Y4 Distance]

= [

Fz
Mx

My]

[
C1,1 | C1,2 | C1,3 | C1,4 | C1,5 | C1,6 | C1,7 | C1,8 | C1,9 | C1,10 | C1,11 | C1,12
C2,1 | C2,2 | C2,3 | C2,4 | C2,5 | C2,6 | C2,7 | C2,8 | C2,9 | C2,10 | C2,11 | C2,12
C3,1 | C3,2 | C3,3 | C3,4 | C3,5 | C3,6 | C3,7 | C3,8 | C3,9 | C3,10 | C3,11 | C3,12] ×

[

Count 1
Count 2
Count 3
Count 4
X1 Distance
Y1 Distance
X2 Distance
Y2 Distance
X3 Distance
Y3 Distance
X4 Distance
Y4 Distance]

= [

Fz
Mx

My]

[C] = [

0.967 −4.989 −8.805 5.938 357.216 −6.199 196.438 −583.162 179.471 −211.860 437.636 −16.777 0.018 −0.129 0.191 −0.093 −5.519 −9.868 −0.999 −3.020 2.784 2.154 10.953 5.718 0.277 0.001 −0.311 0.010 4.356 1.110 1.546 −10.231 −5.456 7.279 −1.956 5.554

] × 10⁻³

Using the data from 1, 6, 7, 8 and 9 in Figure 24 the Fz, Mx and My is predicted to

validate the accuracy and reliability of the scale by comparing the actual results to the

predicted results. The nonlinearity, crosstalk, and hysteresis were also calculated.

Below are the equations used for calculating these terms:

Error(%) =

(Real Load − Measure Load)
Full Load | × 100

Nonlinearity(%) =

(Max.Deviation from regressed line)
Full Load | × 100

Crosstalk(%) = C0 =

Fi
Fj

× 100 ∶ ratio of i − Axis out & j − Axis Out

Repeatability(%) =

Std.Deviation of repeated measure
Full Load | × 100

Hysteresis(%) =

Max.Difference of Output between loading & unloading
Full Load | × 100

The risk assessment for the methodology can be found in Appendix E

### 4 Analysis and Results

Table 1:Experimental Configuration of the Applied Loads for Calibration

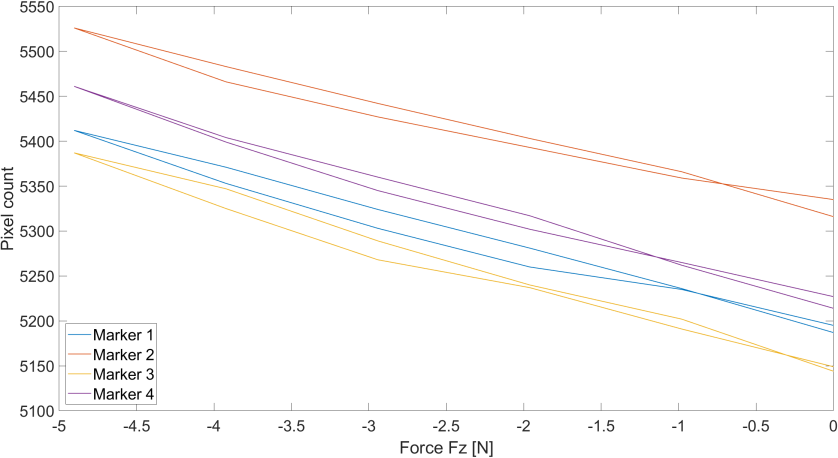
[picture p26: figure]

Figure 25: Characteristic Curve between the loads Fz, and the pixel count

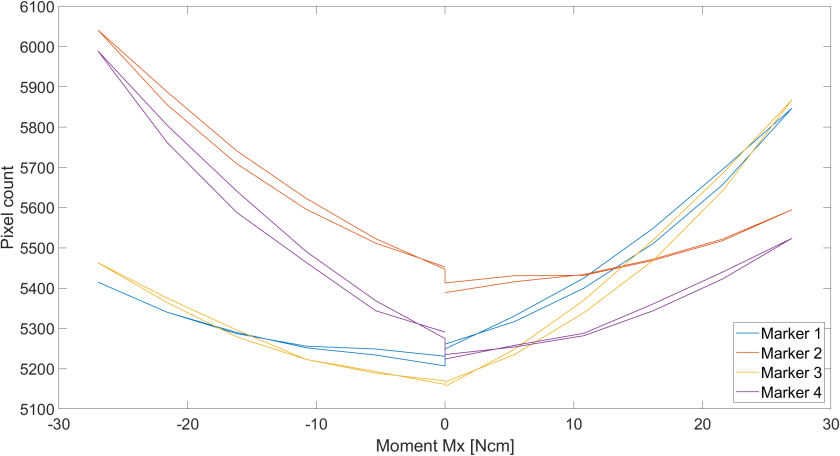
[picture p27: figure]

Figure 26: Characteristic curve between the loads Fz Mx, and the pixel count

Positions on calibration base (see Fig. 23) | Force and Moment component | Force/Moment ranges
1 | Fz | -4.90N to 0N
6 | Fz Mx | -4.90N to 0N 0Ncm to 26.97Ncm
7 | Fz Mx | -4.90N to 0N -26.97Ncm to 0Ncm
9 | Fz My | -4.90N to 0N 0Ncm to 12.26Ncm
8 | Fz My | -4.90N to 0N -12.26Ncm to 0Ncm

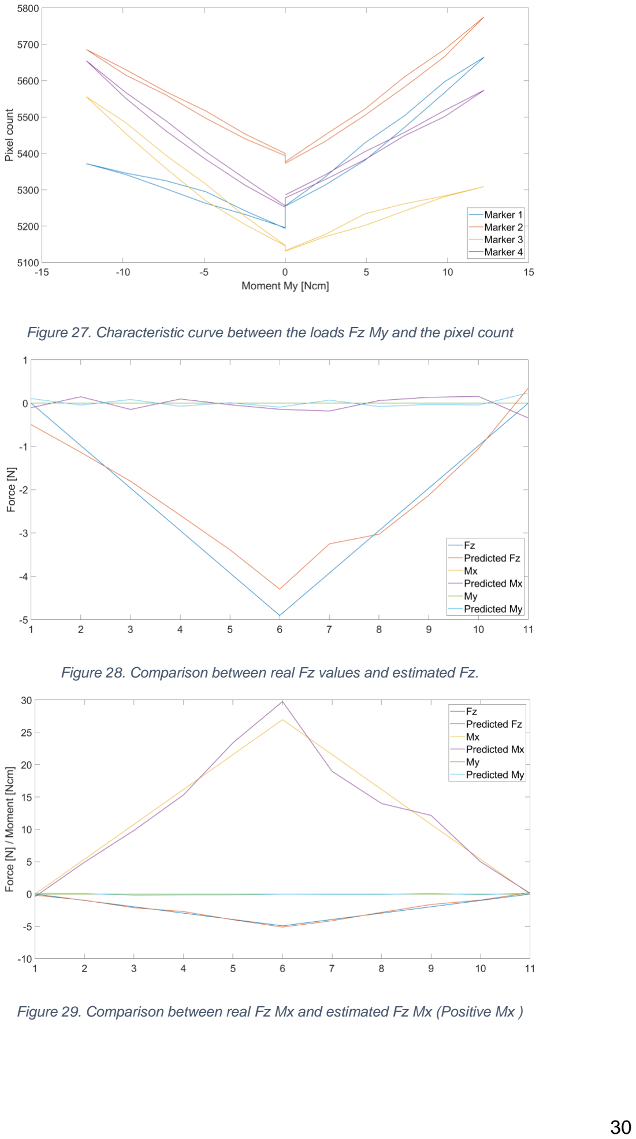
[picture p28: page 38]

Figure 27. Characteristic curve between the loads Fz My and the pixel count

Figure 28. Comparison between real Fz values and estimated Fz.

Figure 29. Comparison between real Fz Mx and estimated Fz Mx (Positive Mx )

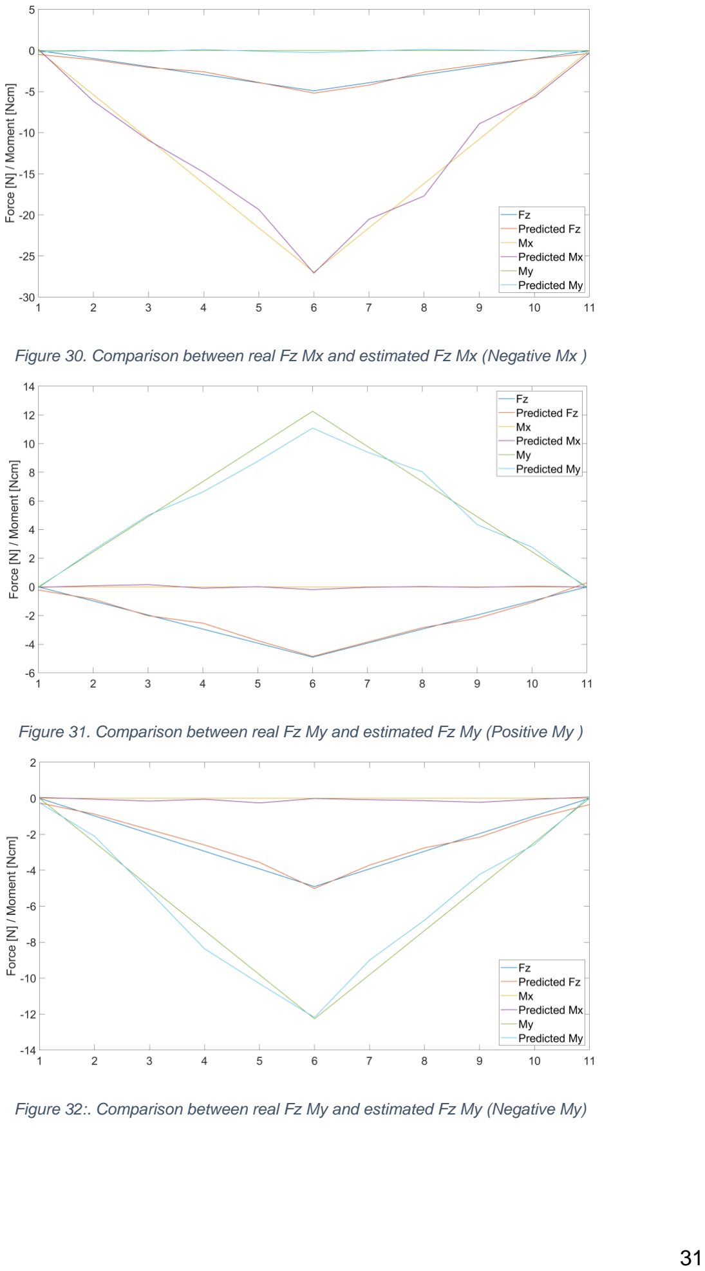
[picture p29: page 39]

Figure 30. Comparison between real Fz Mx and estimated Fz Mx (Negative Mx )

Figure 31. Comparison between real Fz My and estimated Fz My (Positive My )

Figure 32:. Comparison between real Fz My and estimated Fz My (Negative My)

Table 2: Sensor Performance Property: Range, Error and Non-linearity

Force / Moment | Range | Maximum Error | Nonlinearity (%)
Fz | -4.90N to 0N | 0.35 N (18.08%) | 13.73
Mx | -26.97N to 26.97N | 1.87 Ncm (17.29%) | 9.62
My | -12.26N to 12.26N | 0.34 Ncm (13.83%) | 13.82

Table 3: Sensor Performance: Repeatability and Hysteresis

Force / Moment | Repeatability (%) | Hysteresis (%)
Fz | 4.29 | 9.05
Mx | 5.74 | 7.42
My | 3.88 | 11.71

Table 4: Sensor Performance Property: Crosstalk

Force / Moment | Crosstalk (%)
Fz | Fz Mx | Fz My
+Mx | -Mx | +My | -My
Fz | Fz | Fz | Fz | Fz | Fz
Mx | 15.80 | Mx | Mx | 11.48 | 8.10
My | 4.50 | 8.98 | 5.91 | My | My

The estimated Fz, Mx, and My are compared with the ground-truth values of the Fz,

Mx and My, shown in Figure 28-32 and Table 2. It was observed that the maximum

error for Fz is 0.35 N (18.08%) as depicted in Table 2. The maximum error for Mx is

1.87Ncm (17.89%) as depicted in Table 2. The maximum error for My is 0.34 Ncm

(13.83%) as depicted in Table 2. Nevertheless, the calibration matrix can estimate the

force and the moments within a sensor range of Fz (-4.9 N to +4.9 N), Mx (-26.97Ncm

to +26.97Ncm) and My (-12.26 Ncm to +12.26 Ncm) with a maximum absolute and

percentage error.

The nonlinearity of the Fz, Mx and My are shown in Figure 28-32 and Table 2. Looking

at Figures 27-31 it can be seen that the Fz , Mx and My are fairly linear. The

characteristic curves as seen in Figure 25-27 are not absolutely linear and show an

exponential increase when a force is applied

The results of the repeatability test are presented in Table 3, showing the capability of

the force sensor in reproducing the same condition of the force, and two moments. It

can be seen that the maximum percentage repeatability for Fz, Mx and My is 4.29%,

5.74% and 3.88% respectively.

The results of the hysteresis tests are shown in Table 3; an external force is applied

onto the main body from zero to the maximum value, and then released from the

maximum to zero again. During one cycle, the characteristic curves exhibit a

considerable hysteresis as shown in Figures 25-27. The maximum percentage of

hysteresis for Fz, Mx and My is 9.05%, 7.42% and 11.71% respectively.

The crosstalk between force Fz and moments Mx and My is detailed in Table 4. Ideally,

Mx and My should remain zero when Fz is applied, and similarly for other

combinations. However, crosstalk experiments reveal influence on other readings, as

shown in Figures 28-32. Crosstalk percentages are as follows: 15.80% and 4.50% for

Mx and My when Fz is applied; 8.98% for My when Fz and positive Mx are applied;

5.91% for My when Fz and negative Mx are applied; 11.48% for Mx when Fz and

positive My are applied; and 8.10% for Mx when Fz and negative My are applied (see

respective Figures 28-32).

### 5 Discussion

### 5.1 Interpretation of Results

Looking at the results, the errors and crosstalk are associated with hysteresis, as

shown in Figures 25-27. Due to the hysteresis, the calculated calibration matrix causes

errors and crosstalk in values of the Fz, Mz, and My. It also negatively influences the

repeatability of the sensor. As shown in Table 3 the repeatability errors of Fz, Mx and

My are also relatively high. The hysteresis is likely caused because of the use of ABS

due to its material formulation and processing history. The specific ratio of acrylonitrile,

butadiene, and styrene in the ABS polymer, as well as any additives, can affect its

mechanical properties, including hysteresis. The thermal and mechanical stresses

experienced during processing during 3D printing can affect the microstructure and

material properties of ABS, leading to variations in hysteresis.

### 5.2 Significance of the Project

The portable smartphone scale developed in this project presents an innovative

approach to measuring the mass of objects using image processing technology. To

better understand its strengths and weaknesses, it is essential to compare this method

with existing weighing devices, such as spring scales, electronic scales, or hydraulic

scales.

One of the main advantages of the portable smartphone scale is its cost-effectiveness.

By leveraging widely available smartphones and using affordable materials such as a

3D-printed platform and a webcam, this method can be significantly cheaper than

traditional weighing devices, making it more accessible to a broader audience.

The portable smartphone scale is also user-friendly and can be operated with minimal

training. The process of weighing objects involves simply placing them on the platform

and using a smartphone to capture images. This simplicity contrasts with some

traditional weighing devices that may require specific knowledge or expertise to

operate.

Additionally, the compact and lightweight nature of the smartphone scale makes it

highly portable, allowing users to weigh objects virtually anywhere. In comparison,

traditional weighing devices like electronic or hydraulic scales may be bulky or heavy,

limiting their portability and usability in various settings.

However, while the smartphone scale has demonstrated its potential in measuring

mass using image processing techniques, it might not yet achieve the same level of

precision and accuracy as some traditional weighing devices, especially those

designed for measuring very small or large masses. Factors such as lighting

conditions and surface irregularities can also influence the accuracy of the image

processing algorithm.

In terms of reliability, traditional weighing devices like electronic or hydraulic scales

may have well-established track records, whereas the portable smartphone scale is a

relatively new concept. Although this project has shown the feasibility of using image

processing for mass measurement, further research and development are needed to

ensure the system's long-term reliability.

Finally, the portable smartphone scale can be advantageous in situations where

traditional weighing devices are impractical, such as field research or remote locations.

However, its applicability in specific industries or applications might be limited

compared to specialized weighing devices designed for precise purposes, like medical

or scientific research.

In summary, the portable smartphone scale offers several advantages over traditional

weighing devices, including cost, ease of use, and portability. While its accuracy and

reliability might not yet surpass that of established weighing devices, the smartphone

scale presents a promising alternative that can be further improved through ongoing

research and development.

### 5.3 Limitations

During the course of this project, certain limitations and assumptions were

encountered, which may have influenced the results and overall performance of the

developed system.

One limitation is the accuracy of the 3D-printed platform. The precision of the 3D-

printed platform might not be perfect, potentially introducing errors in the

measurements. Slight deviations in the geometry or material properties of the

platform could impact the system's ability to accurately measure mass.

Another limitation is the resolution of the webcam used in the project, which can

affect the accuracy of the image processing algorithm. Lower resolution images may

not provide sufficient detail to accurately detect the markers, leading to

measurement errors.

Additionally, the calibration using fixed masses might not represent the full range of

weights the system is expected to measure. This limitation could result in

inaccuracies when weighing objects that fall outside of the calibration range.

Moreover, the performance of the image processing algorithm can be influenced by

the lighting conditions under which the experiments are conducted. Shadows,

reflections, or glare may interfere with the detection of markers and impact the

accuracy of the system.

Finally, the system assumes that the object being weighed is placed evenly on the

platform. Any uneven distribution of weight or misalignment could introduce

inaccuracies in the mass measurement.

By acknowledging these limitations and assumptions, we can better understand the

potential sources of error in the project and identify areas for future improvement.

Addressing these concerns in subsequent iterations can enhance the overall

performance and accuracy of the system.

### 6 Conclusions

### 6.1 Conclusions from the Investigation

This project has successfully demonstrated the feasibility of developing a low-cost,

portable scale using a smartphone and image processing technology. By utilizing a

3D-printed platform, a webcam, and image processing algorithms in MATLAB, the

system offers an innovative approach to mass measurement that is accessible, user-

friendly, and portable.

While the portable smartphone scale may not yet achieve the same level of accuracy

and reliability as some traditional weighing devices, the project has shown its potential

in various applications, including everyday use, field research, and education. The

technology offers a promising alternative to conventional weighing methods, and with

further research and development, its performance and versatility can continue to

improve.

Comparisons with existing methods have highlighted the strengths of the portable

smartphone scale, such as cost-effectiveness, ease of use, and portability. However,

these comparisons have also revealed areas where the system could be improved,

including accuracy, reliability, and applicability in specialized industries or applications.

In conclusion, the portable smartphone scale represents a significant advancement in

mechanical engineering and related disciplines, showcasing the potential of image

processing technology and smartphone integration in creating accessible and

affordable weighing solutions. This project serves as an inspiring example of

innovation, collaboration, and progress in the field of engineering.

### 6.2 Suggestions for Further Work

Several areas can be explored to improve the performance, accuracy, and versatility

of the portable smartphone scale, making it even more useful and relevant across

various sectors.

One area is the enhancement of the image processing algorithm. Developing and

implementing a more sophisticated algorithm can improve marker detection and

measurement accuracy. Machine learning and advanced computer vision algorithms can be employed to increase the system's robustness against various lighting

conditions and surface irregularities.

Another improvement can be achieved by utilizing higher-resolution cameras, possibly

built into smartphones. This would result in more detailed images, which can improve

the detection and measurement of markers, leading to increased accuracy and

consistency in mass measurements.

Incorporating other types of sensors, such as accelerometers or pressure sensors,

can also enhance the system's ability to account for irregularities in object placement

or surface conditions. These sensors can provide supplementary data to improve

measurement accuracy and compensate for potential sources of error.

Developing a more comprehensive calibration method that considers a wider range of

masses or dynamically adjusts to the specific weighing conditions can lead to

increased accuracy across different mass ranges and environmental factors.

Furthermore, optimizing the 3D-printed platform design by experimenting with different

materials, geometries, and fabrication techniques can improve its precision and

stability, contributing to a more consistent and accurate measurement system.

Finally, expanding the range of applications by investigating the system's applicability

to various industries and specific use cases can widen its utility. For example,

exploring its potential in areas like medical and pharmaceutical applications, precision

agriculture, or geological sampling can lead to new opportunities for the portable

smartphone scale.

By focusing on these future work and improvements, the portable smartphone scale

can continue to evolve, providing more accurate, reliable, and versatile mass

measurement solutions for users in different fields. The pursuit of these enhancements

will further contribute to the ongoing growth and innovation within mechanical

engineering and related disciplines.

### 7 References

[1] - Coppetti, T., Brauchlin, A., Müggler, S., Attinger-Toller, A., Templin, C., Schönrath, F.,

Hellermann, J., Lüscher, T.F., Biaggi, P. and Wyss, C.A., 2017. Accuracy of smartphone apps for

heart rate measurement. European journal of preventive cardiology, 24(12), pp.1287-1293.

[2] - Demırezen, H. and Erdem, Ç.E., 2017, May. An overview of non-contact

photoplethysmography. In 2017 25th Signal Processing and Communications Applications

Conference (SIU) (pp. 1-4). IEEE.

[3] – Mehta, H., Kanani, P. and Lande, P., 2019. Google maps. International Journal of Computer

Applications, 178(8), pp.41-46.

[4] - Morawska, L., Thai, P.K., Liu, X., Asumadu-Sakyi, A., Ayoko, G., Bartonova, A., Bedini, A.,

Chai, F., Christensen, B., Dunbabin, M. and Gao, J., 2018. Applications of low-cost sensing

technologies for air quality monitoring and exposure assessment: How far have they

gone?. Environment international, 116, pp.286-299.

[5] - Lashin, M.M., 2014. Different applications of programmable logic controller

(PLC). International Journal of Computer Science, Engineering and Information Technology

(IJCSEIT), 4(1), pp.27-32.

[6] - Seng, W.C. and Mirisaee, S.H., 2009, August. A new method for fruits recognition system.

In 2009 International conference on electrical engineering and informatics (Vol. 1, pp. 130-134).

IEEE. [7] - Mojekwu, T.O. and Anumudu, C.I., 2015. Advanced techniques for morphometric

analysis in fish. Journal of Aquaculture Research & Development, 6(8), pp.1-6.

[8] - Silva, J.P.M., da Silva, M.L.M., da Silva, E.F., da Silva, G.F., de Mendonca, A.R., Cabacinha,

C.D., Araujo, E.F., Santos, J.S., Vieira, G.C., de Almeida, M.N.F. and de Moura Fernandes, M.R.,

2019. Computational techniques applied to volume and biomass estimation of trees in Brazilian

savanna. Journal of environmental management, 249, p.109368.

[9] - Salinas, R.A., Raff, U. and Farfan, C., 2005. Automated estimation of rock fragment

distributions using computer vision and its application in mining. IEE Proceedings-Vision, Image

and Signal Processing, 152(1), pp.1-8

[10] - Tomin, M., Török, D., Pászthy, T. and Kmetty, Á., 2023. Deformation analysis in impact

testing of functionally graded foams by the image processing of high-speed camera

recordings. Polymer Testing, p.108014.

[11] - Kalantar, A., Edan, Y., Gur, A. and Klapp, I., 2020. A deep learning system for single and

overall weight estimation of melons using unmanned aerial vehicle images. Computers and

Electronics in Agriculture, 178, p.105748.

[12] – Bansal, A., Bajpai, R. and Saini, J.P., 2007, March. Simulation of image enhancement

techniques using Matlab. In First Asia International Conference on Modelling & Simulation

(AMS'07) (pp. 296-301). IEEE.

[13] – Agrawal, P., Shriwastava, S.K. and Limaye, S.S., 2010, July. MATLAB implementation of

image segmentation algorithms. In 2010 3rd International Conference on Computer Science and

Information Technology (Vol. 3, pp. 427-431). IEEE.

[14] – Sharma, D., 2013. 2D to 3D Conversion Using SINGLE Input by Spatial Transformation

Using MATLAB. International Journal of Emerging Technology and Advanced Engineering, 3(1).

[15] – Arzuaga-Cruz, E., Jimenez-Rodriguez, L.O., Velez-Reyes, M., Kaeli, D., Rodriguez-Diaz,

E., Velazquez-Santana, H.T., Castrodad-Carrau, A., Santos-Campis, L.E. and Santiago, C.,

2004, September. A MATLAB toolbox for hyperspectral image analysis. In IGARSS 2004. 2004

IEEE International Geoscience and Remote Sensing Symposium (Vol. 7, pp. 4839-4842). IEEE.

[16] – Kumar, T. and Verma, K., 2010. A Theory Based on Conversion of RGB image to Gray

image. International Journal of Computer Applications, 7(2), pp.7-10.

[17] – Dangphonthong, D. and Pinate, W., 2016, January. Analysis of weight egg using image

processing. In Proceedings of Academics World 17th International Conference. Tokyo,

Japan (pp. 55-57).

[18] - Sharma, R., Kumar, M. and Alam, M.S., 2021. Image processing techniques to estimate

weight and morphological parameters for selected wheat refractions. Scientific Reports, 11(1),

p.20953.

[19] - 120cm Portable Aluminum Folding Table Party garden BBQ camping table, 3 gear

adjustable height lightweight aluminum foldable table for outdoor picnic cooking, white, unfolding

size: 120X60X70/62/55cm (no date) Amazon.co.uk: Home & Kitchen

[20] - Noh, Y., Sareh, S., Würdemann, H., Liu, H., Back, J., Housden, J., Rhode, K. and Althoefer,

K., 2015. Three-axis fiber-optic body force sensor for flexible manipulators. IEEE Sensors

Journal, 16(6), pp.1641-1651.

App XLI

Appendices

Appendix A – Management of the Project

Task | Expected Start Date | Expected End Date | Duration
Literature review | 01/10/2022 | 22/10/2022 | 21
Selection of CAD software and programming language | 23/10/2022 | 28/10/2022 | 5
Conceptual design | 29/10/2022 | 12/11/2022 | 14
CAD Modelling and design refinement | 13/11/2022 | 27/11/2022 | 14
Finite Element Analysis (FEA) | 28/11/2022 | 05/12/2022 | 7
Development of computer vision application and GUI | 06/12/2022 | 20/12/2022 | 14
Prototype fabrication | 21/12/2022 | 13/01/2023 | 23
Calibration and validation | 14/01/2023 | 26/01/2023 | 12
Analysis of potential applications and market demand | 27/01/2023 | 03/02/2023 | 7
Final report writing and documentation | 04/02/2023 | 24/04/2023 | 79
Poster and presentation preparation | 01/04/2023 | 24/04/2023 | 23

The project ended up taking longer than expected because of many reasons. One of the main reasons was personal issues which substantially delayed initial progress in the project. Once the project

was started many issues were encountered during the ‘Prototype fabrication’ stage of the project. This is because there were many issues with the 3D printers repeatedly failing prints as well as a

period of time where there was no filament available.

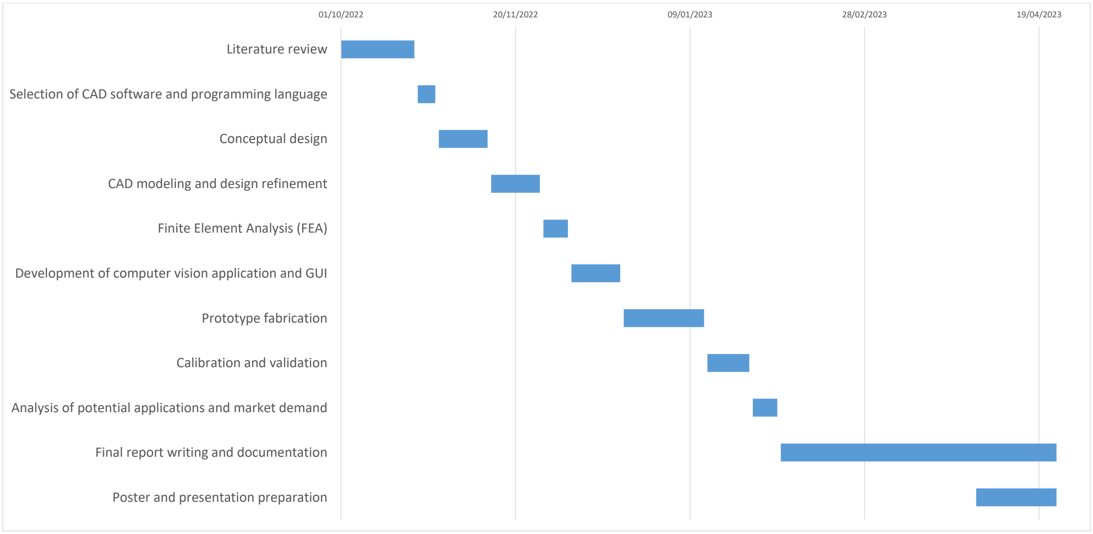
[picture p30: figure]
Literature review; Conceptual design; CAD modeling and design refinement; Finite Element Analysis (FEA); Prototype fabrication; Calibration and validation; Final report writing and documentation; Poster and presentation preparation

App XLII

Appendix A.1 Project Gantt Chart

01/10/2022 | 20/11/2022 | 09/01/2023 | 28/02/2023 | 19/04/2023

### Selection of CAD software and programming language

### Development of computer vision application and GUI

### Analysis of potential applications and market demand

App XLIII

Appendix B – GUI MATLAB Script

% Initialize the camera
cam = webcam();

% Create the GUI window
fig = uifigure('Name', 'Image Analysis'); fig.Position = [200 200 700 500];

% Create the image axes
imgAxes = uiaxes('Parent', fig, 'Position', [50 50 400 400]);

% Create the text labels for displaying the pixel count and centroid positions labelPos = [450 350 100 20];
labelCount1 = uilabel('Parent', fig, 'Position', labelPos);
labelCount2 = uilabel('Parent', fig, 'Position', labelPos + [0 -50 0 0]); labelCount3 = uilabel('Parent', fig, 'Position', labelPos + [0 -100 0 0]); labelCount4 = uilabel('Parent', fig, 'Position', labelPos + [0 -150 0 0]);

labelPos = [550 400 100 20];
labelCentroidX1 = uilabel('Parent', fig, 'Position', labelPos); labelCentroidX2 = uilabel('Parent', fig, 'Position', labelPos + [0 -50 0 0]); labelCentroidX3 = uilabel('Parent', fig, 'Position', labelPos + [0 -100 0 0]); labelCentroidX4 = uilabel('Parent', fig, 'Position', labelPos + [0 -150 0 0]);

labelPos = [550 200 100 20];
labelCentroidY1 = uilabel('Parent', fig, 'Position', labelPos); labelCentroidY2 = uilabel('Parent', fig, 'Position', labelPos + [0 -50 0 0]); labelCentroidY3 = uilabel('Parent', fig, 'Position', labelPos + [0 -100 0 0]); labelCentroidY4 = uilabel('Parent', fig, 'Position', labelPos + [0 -150 0 0]);

labelPos = [650 200 100 20];
labelMass = uilabel('Parent', fig, 'Position', labelPos);

% Create the main loop for capturing and processing the image while isvalid(fig)
% Capture the image from the camera
img = snapshot(cam);

% Apply Gaussian filter
img_filtered = imgaussfilt(img, 4); % The second argument is the standard deviation of the Gaussian filter

% Convert the image to grayscale
bwImg = im2bw(img_filtered);

% Split the binary image into 4 equal sections [h, w] = size(bwImg);
sectionWidth = w/2;
sectionHeight = h/2;

section1 = bwImg(1:sectionHeight, 1:sectionWidth); section2 = bwImg(1:sectionHeight, sectionWidth+1:end); section3 = bwImg(sectionHeight+1:end, 1:sectionWidth); section4 = bwImg(sectionHeight+1:end, sectionWidth+1:end);

% Count the number of white pixels in each section count1 = sum(section1(:));
count2 = sum(section2(:));
count3 = sum(section3(:));
count4 = sum(section4(:));

% Compute the centroid positions of the white pixels in each section props1 = regionprops(section1, 'Centroid');
props2 = regionprops(section2, 'Centroid');

App XLIV

props3 = regionprops(section3, 'Centroid'); props4 = regionprops(section4, 'Centroid');

if ~isempty(props1)
centroid1 = props1(1).Centroid;
else
centroid1 = [NaN NaN];
end

if ~isempty(props2)
centroid2 = props2(1).Centroid; else
centroid2 = [NaN NaN];
end

if ~isempty(props3)
centroid3 = props3(1).Centroid; else
centroid3 = [NaN NaN];
end

if ~isempty(props4)
centroid4 = props4(1).Centroid; else
centroid4 = [NaN NaN];
end

% Compute the x and y distance of each centroid from the center of the whole image center = [w/2 h/2];

if ~isnan(centroid1)
dist1 = centroid1 - center; xDist1 = -dist1(1);
yDist1 = -dist1(2);
xDist1 = round(xDist1);
yDist1 = round(yDist1);
else
xDist1 = NaN;
yDist1 = NaN;
end

if ~isnan(centroid2)
dist2 = centroid2 - center;

xDist2 = centroid2(1);
yDist2 = -dist2(2);
xDist2 = round(xDist2);
yDist2 = round(yDist2);
else
xDist2 = NaN;
yDist2 = NaN;
end

if ~isnan(centroid3)
dist3 = centroid3 - center; xDist3 = -dist3(1);
yDist3 = centroid3(2);
xDist3 = round(xDist3);
yDist3 = round(yDist3);
else
xDist3 = NaN;
yDist3 = NaN;

end

if ~isnan(centroid4)
dist4 = centroid4 - center;

App XLV

xDist4 = centroid4(1);
yDist4 = centroid4(2);
xDist4 = round(xDist4);
yDist4 = round(yDist4);
else
xDist4 = NaN;
yDist4 = NaN;
end
C = [-0.0104168629833224 -0.00944917403780000 | -0.0230974827719833
0.00729259966113088 | -0.118004606975970 | 0.754709747649660
-0.243793005361824 | -0.154573237617072 | 0.230557722618885
0.535561085233072 | 0.401978711937218 | 0.289650104588845
1.83762912284827e-06 | -0.000143896119637691 | 0.000199604850738702 | -
0.000101329187907418 | -0.00283636198871067 | -0.00850192383249774 | -
0.00102472041128066 | -0.00107521427393267 | -0.00133288102373877
0.00449615965863117 | 0.00907332663274933 | 0.00471568559239377
0.000274456981798683 | -5.43375482731146e-06 | -0.000287773457796409 | -
2.56075659981518e-05 | 0.00480186166884118 | -0.00131996042694900
0.00204177305680907 | -0.00608963909954442 | -0.00693098041141154
0.00949937042098853 | -0.00348653848228535 | 0.00468544264849634];

X =
[count1;count2;count3;count4;xDist1;yDist1;xDist2;yDist2;xDist3;yDist3;xDist4;yDist 4];

FMM = C * X;

Mass = FMM()

% Display the binary image and the results in the GUI imshow(bwImg, 'Parent', imgAxes);

labelCount1.Text = sprintf('Count 1: %d', count1); labelCount2.Text = sprintf('Count 2: %d', count2); labelCount3.Text = sprintf('Count 3: %d', count3); labelCount4.Text = sprintf('Count 4: %d', count4);

labelCentroidX1.Text = sprintf('X1: %d', xDist1); labelCentroidX2.Text = sprintf('X2: %d', xDist2); labelCentroidX3.Text = sprintf('X3: %d', xDist3); labelCentroidX4.Text = sprintf('X4: %d', xDist4);

labelCentroidY1.Text = sprintf('Y1: %d', yDist1); labelCentroidY2.Text = sprintf('Y2: %d', yDist2); labelCentroidY3.Text = sprintf('Y3: %d', yDist3); labelCentroidY4.Text = sprintf('Y4: %d', yDist4);

labelMass.Text = sprintf('Mass: %d', Mass);

drawnow;
end

% Clean up
delete(cam);
delete(fig);

App XLVI

Appendix C – Plotting MATLAB Script

% Initialize webcam
cam = webcam();

% Create the first figure
fig1 = figure;

% Initialize the x-axis and y-axis data for figure 1 x1 = 0;
y1 = [0, 0, 0, 0];

% Create the second figure
fig2 = figure;

% Initialize the x-axis and y-axis data for figure 2 x2 = 0;
y2 = [0, 0, 0, 0, 0, 0, 0, 0];

% Start the loop
while isvalid(fig1) && isvalid(fig2)
% Capture the image from the camera img = snapshot(cam);

% Apply Gaussian filter
img_filtered = imgaussfilt(img, 4); % The second argument is the standard deviation of the Gaussian filter

% Convert the image to grayscale
bwImg = im2bw(img_filtered);

% Split the binary image into 4 equal sections [h, w] = size(bwImg);
sectionWidth = w/2;
sectionHeight = h/2;

section1 = bwImg(1:sectionHeight, 1:sectionWidth); section2 = bwImg(1:sectionHeight, sectionWidth+1:end); section3 = bwImg(sectionHeight+1:end, 1:sectionWidth); section4 = bwImg(sectionHeight+1:end, sectionWidth+1:end);

% --- Update the first figure ---
figure(fig1); % Set the focus on the first figure

% Count the number of white pixels in each section count1 = sum(section1(:));
count2 = sum(section2(:));
count3 = sum(section3(:));
count4 = sum(section4(:));

% Update the x-axis data for figure 1 x1 = [x1, x1(end)+1];

% Update the y-axis data for figure 1
y1 = [y1; [count1, count2, count3, count4]];

% Update the line plot for figure 1 plot(x1, y1);
title('Live Count');
xlabel('Time (s)');
ylabel('Count');
legend('Section 1', 'Section 2', 'Section 3', 'Section 4')

% Set the y-axis limits for figure 1
ylim([4500, 6500]);

App XLVII

% --- Update the second figure ---
figure(fig2); % Set the focus on the second figure

% Calculate the centroids for each section
props1 = regionprops(section1, 'Centroid'); props2 = regionprops(section2, 'Centroid'); props3 = regionprops(section3, 'Centroid'); props4 = regionprops(section4, 'Centroid');

if ~isempty(props1)
centroid1 = props1(1).Centroid;
else
centroid1 = [NaN NaN];
end

if ~isempty(props2)
centroid2 = props2(1).Centroid; else
centroid2 = [NaN NaN];
end

if ~isempty(props3)
centroid3 = props3(1).Centroid; else
centroid3 = [NaN NaN];
end

if ~isempty(props4)
centroid4 = props4(1).Centroid; else
centroid4 = [NaN NaN];
end

% Compute the x and y distance of each centroid from the center of the whole image center = [w/2 h/2];

if ~isnan(centroid1)
dist1 = centroid1 - center; xDist1 = -dist1(1);
yDist1 = -dist1(2);
xDist1 = round(xDist1);
yDist1 = round(yDist1);
else
xDist1 = NaN;
yDist1 = NaN;
end

if ~isnan(centroid2)
dist2 = centroid2 - center;

xDist2 = centroid2(1);
yDist2 = -dist2(2);
xDist2 = round(xDist2);
yDist2 = round(yDist2);
else
xDist2 = NaN;
yDist2 = NaN;
end

if ~isnan(centroid3)
dist3 = centroid3 - center; xDist3 = -dist3(1);
yDist3 = centroid3(2);
xDist3 = round(xDist3);
yDist3 = round(yDist3);
else
xDist3 = NaN;

App XLVIII

yDist3 = NaN;

end

if ~isnan(centroid4)
dist4 = centroid4 - center; xDist4 = centroid4(1);
yDist4 = centroid4(2);
xDist4 = round(xDist4);
yDist4 = round(yDist4);
else
xDist4 = NaN;
yDist4 = NaN;
end

x2 = [x2, x2(end)+1];

% Update the y-axis data for figure 2
y2 = [y2; [xDist1, yDist1, xDist2, yDist2, xDist3, yDist3, xDist4, yDist4]];

% Update the line plot for figure 2
plot(x2, y2);
title('Live Distance');
xlabel('Time (s)');
ylabel('Distance');
legend('X1', 'Y1', 'X2', 'Y2', 'X3', 'Y3', 'X4', 'Y4')

% Set the y-axis limits for figure 2
ylim([80, 140]);

% Pause for a short time
pause(0.01);
end

% Release the webcam
clear cam;

App XLIX

Appendix D – Calibration MATLAB Script

close all

% Load the data
data = xlsread('ALL_IN_ONE.xlsx'); X = data(1:55,4:15);
Y = data(1:55,1:3);

Xt = transpose(X);
Yt = transpose(Y);

calibration_matrix = zeros(3, 12);

% Perform linear regression using 'regress' function for each output component for i = 1:3
calibration_matrix(i, :) = regress(Y(:, i), X);
end

predicted = calibration_matrix * Xt;

Pos1x = transpose(data(1:11,4:15)); Pos2x = transpose(data(12:22,4:15)); Pos3x = transpose(data(23:33,4:15)); Pos4x = transpose(data(34:44,4:15)); Pos5x = transpose(data(45:55,4:15)); Pos6x = transpose(data(56:66,4:15)); Pos7x = transpose(data(67:77,4:15)); Pos8x = transpose(data(78:88,4:15)); Pos9x = transpose(data(89:99,4:15));

Pos1 = calibration_matrix * Pos1x; Pos2 = calibration_matrix * Pos2x; Pos3 = calibration_matrix * Pos3x; Pos4 = calibration_matrix * Pos4x; Pos5 = calibration_matrix * Pos5x; Pos6 = calibration_matrix * Pos6x; Pos7 = calibration_matrix * Pos7x; Pos8 = calibration_matrix * Pos8x; Pos9 = calibration_matrix * Pos9x;

figure(1)
plot(data(1:11,1),'LineWidth',1); hold on
plot(Pos1(1,:),'LineWidth',1); hold on
plot(data(1:11,2),'LineWidth',1); hold on
plot(Pos1(2,:),'LineWidth',1); hold on
plot(data(1:11,3),'LineWidth',1); hold on
plot(Pos1(3,:),'LineWidth',1);

legend('Fz', 'Predicted Fz','Mx', 'Predicted Mx', 'My', 'Predicted My'); ylabel('Force [N]')
set(legend,'FontSize',20);
legend('Location','southeast')
set(gca,'FontSize',20);

App L

figure(2)
plot(data(56:66,1),'LineWidth',1); hold on
plot(Pos6(1,:),'LineWidth',1); hold on
plot(data(56:66,2),'LineWidth',1); hold on
plot(Pos6(2,:),'LineWidth',1); hold on
plot(data(56:66,3),'LineWidth',1); hold on
plot(Pos6(3,:),'LineWidth',1);

legend('Fz', 'Predicted Fz','Mx', 'Predicted Mx', 'My', 'Predicted My'); ylabel('Force [N] / Moment [Ncm]')
set(legend,'FontSize',20);
legend('Location','northeast')
set(gca,'FontSize',20);

figure(3)
plot(data(67:77,1),'LineWidth',1); hold on
plot(Pos7(1,:),'LineWidth',1); hold on
plot(data(67:77,2),'LineWidth',1); hold on
plot(Pos7(2,:),'LineWidth',1); hold on
plot(data(67:77,3),'LineWidth',1); hold on
plot(Pos7(3,:),'LineWidth',1);

legend('Fz', 'Predicted Fz','Mx', 'Predicted Mx', 'My', 'Predicted My'); ylabel('Force [N] / Moment [Ncm]')
set(legend,'FontSize',20);
legend('Location','southeast')
set(gca,'FontSize',20);

figure(4)
plot(data(78:88,1),'LineWidth',1); hold on
plot(Pos8(1,:),'LineWidth',1); hold on
plot(data(78:88,2),'LineWidth',1); hold on
plot(Pos8(2,:),'LineWidth',1); hold on
plot(data(78:88,3),'LineWidth',1); hold on
plot(Pos8(3,:),'LineWidth',1);

legend('Fz', 'Predicted Fz','Mx', 'Predicted Mx', 'My', 'Predicted My'); ylabel('Force [N] / Moment [Ncm]')
set(legend,'FontSize',12);
legend('Location','southeast')
set(gca,'FontSize',20);

figure(5)
plot(data(89:99,1),'LineWidth',1); hold on
plot(Pos9(1,:),'LineWidth',1); hold on
plot(data(89:99,2),'LineWidth',1); hold on
plot(Pos9(2,:),'LineWidth',1); hold on

App LI

plot(data(89:99,3),'LineWidth',1); hold on
plot(Pos9(3,:),'LineWidth',1);

legend('Fz', 'Predicted Fz','Mx', 'Predicted Mx', 'My', 'Predicted My'); ylabel('Force [N] / Moment [Ncm]')
set(legend,'FontSize',20);
legend('Location','northeast')
set(gca,'FontSize',20);

App LII

Appendix E – Risk Assessment

1. Hot Knife

Potential Hazards:

- Burns from hot surfaces or blades
- Fire hazard due to contact with flammable materials
- Cuts from sharp edges

Risk Mitigation Measures:

- Do not use the hot knife near flammable materials
- Handle the hot knife carefully
2. 100g Weights

Potential Hazards:

- Injuries from dropping weights on oneself or others
- Tripping hazards if weights are not stored properly

Risk Mitigation Measures:

- Store weights on proper racks or designated areas
- Keep the work area clear and free from obstacles
3. 3D Printer

Potential Hazards:

- Burns from a hot extruder or heated bed
- Fire hazard due to overheating components or electrical issues

App LIII

- Inhaling toxic fumes from melting materials

Risk Mitigation Measures:

- Operate the 3D printer in a well-ventilated area
- Keep a fire extinguisher nearby when using a 3D printer
- Regularly inspect and maintain the 3D printer, including cleaning the extruder

and checking for loose connections

- Do not touch the extruder or heated bed while in operation
4. Chemical Bath

Potential Hazards:

- Chemical burns or skin irritation from direct contact
- Inhalation of toxic fumes or vapours
- Fire or explosion hazard due to volatile chemicals

Risk Mitigation Measures:

- Wear appropriate personal protective equipment, including gloves, goggles,

and a lab coat

- Work in a well-ventilated area or fume hood
- Store chemicals in appropriate containers and in a designated storage area
- Follow proper chemical disposal procedures
- Keep a fire extinguisher and an eyewash station nearby
5. Electrical Devices

Potential Hazards:

- Electrical shock from damaged cords, plugs, or exposed wiring

App LIV

- Fire hazard due to electrical faults or overloading circuits
- Tripping hazards from cords

Risk Mitigation Measures:

- Regularly inspect electrical devices for damage or wear and replace as

necessary

- Ensure devices are properly grounded and do not overload circuits
- Use surge protectors and avoid using extension cords when possible
- Keep work areas clear of loose cords or clutter that may cause tripping

Keep liquids away from electrical devices to prevent spills and damage

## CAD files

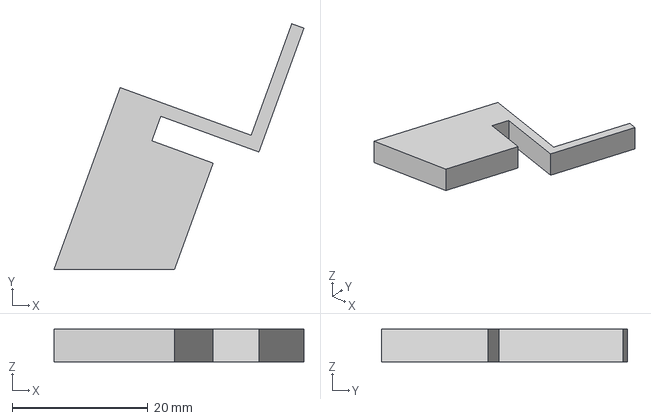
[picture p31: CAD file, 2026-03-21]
CAD/concept_2_v2.step
36.8 x 36.2 x 4.81 mm

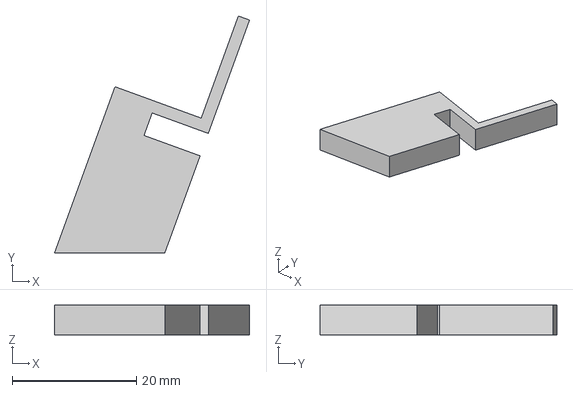
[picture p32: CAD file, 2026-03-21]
CAD/concept_1_v2.step
31.4 x 38.1 x 4.81 mm

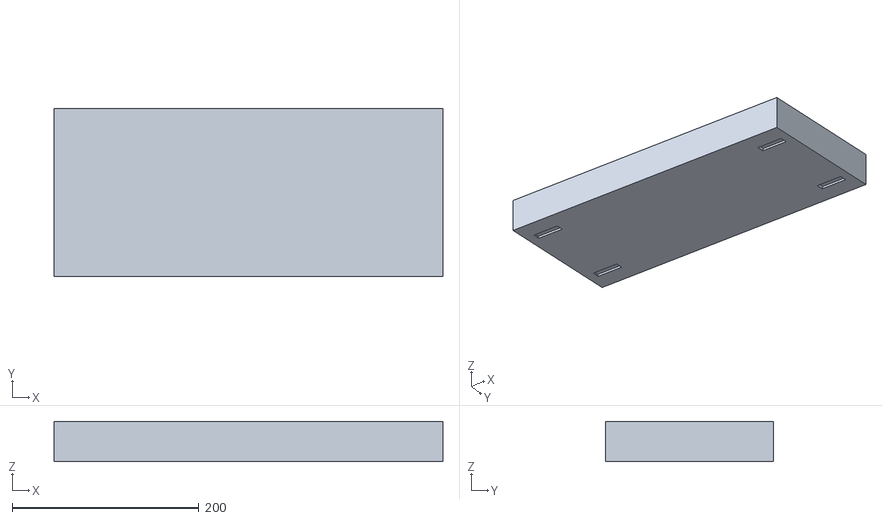
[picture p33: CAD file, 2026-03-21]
CAD/base.stl
416.2 x 180.0 x 43.0

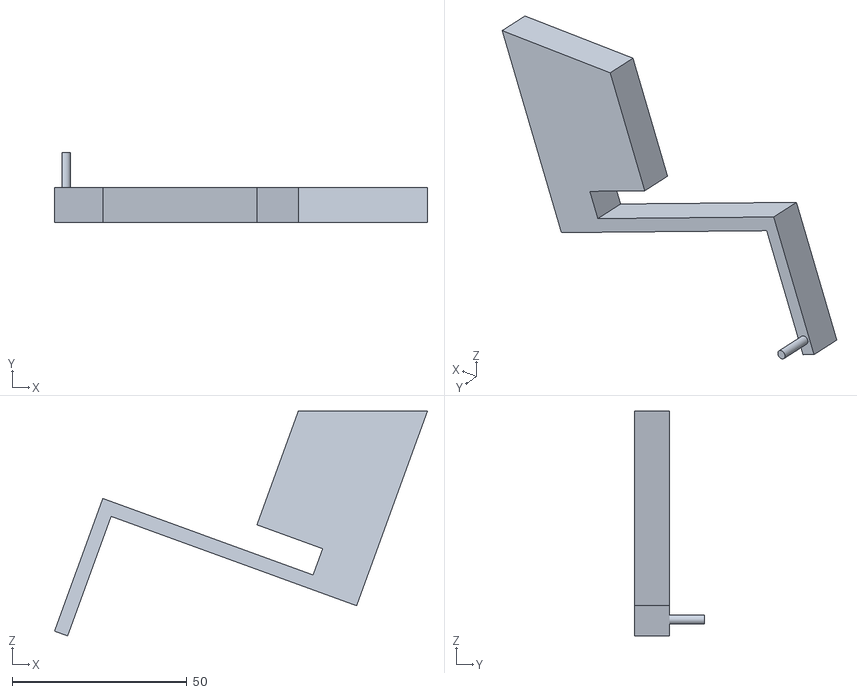
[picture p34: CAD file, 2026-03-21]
CAD/leg_2.stl
106.7 x 20.0 x 64.3

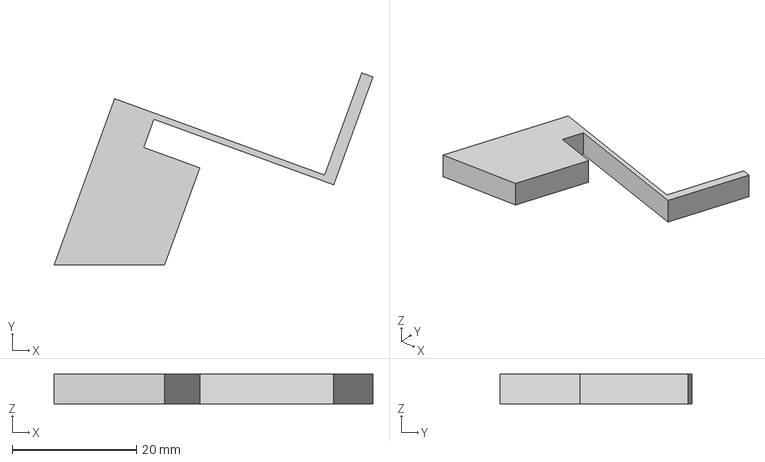
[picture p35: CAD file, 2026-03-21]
CAD/concept_4_v2.step
51.3 x 30.9 x 4.81 mm

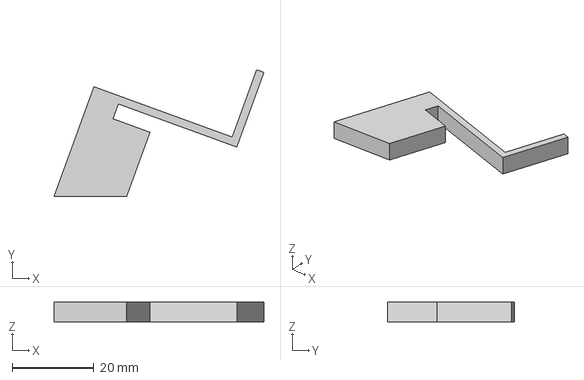
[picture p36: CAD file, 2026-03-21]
CAD/concept_3_v2.step
51.3 x 30.9 x 4.81 mm

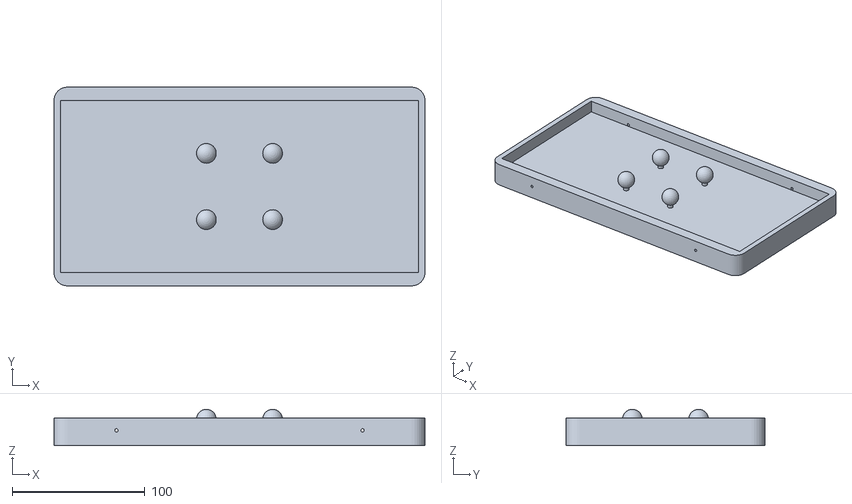
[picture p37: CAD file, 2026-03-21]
CAD/body.stl
280.0 x 150.0 x 27.5

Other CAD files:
CAD/leg_1.stl
CAD/concept_5_v2.step
CAD/concept_6_v2.step

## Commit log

2026-03-21 Upload complete dissertation portfolio: CAD, Scripts, Images, and Data
    [ALL_IN_ONE.xlsx, base.stl, body.stl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]
2026-07-13 fix: prevent crash in gui.m when a tracking marker is lost
    ifelse() was a plain function, so props1(1).Centroid was evaluated
    eagerly even when props1 was empty, throwing an index-out-of-bounds
    error exactly when a marker went out of frame. Replaced with
    get_centroid(), the same real if/else pattern already used in
    plotting.m.
2026-10-02 Correct publication status: submitted but not accepted by IEEE Sensors Letters; preprint on TechRxiv
